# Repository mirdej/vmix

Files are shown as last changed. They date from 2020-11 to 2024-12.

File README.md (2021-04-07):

# ANYMIX 21

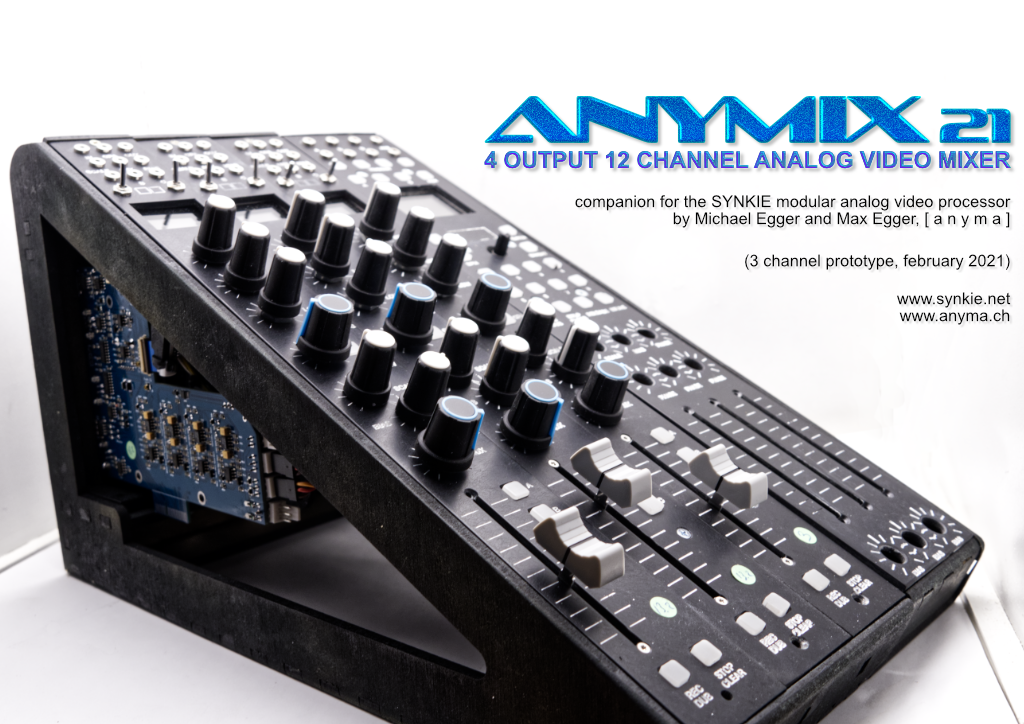
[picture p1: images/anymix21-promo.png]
Product Photo


Multichannel modular analog PAL video mixer based on the SYNKIE project

The Anymix21 is a 12 channel analog video mixer based on the paradigm of classic audio mixing desks.

Each channel is a complete SYNKIE by itself, sort of. It can handle anything from DC to around 10Mhz, this means you can mix CV signals with audio with PAL composite video signals. Contrary to an audio mixer, inputs are DC coupled, with 0v being black and 0.7V white level. Negative levels are permitted but will be clipped at the final output stage.

Each channel has a built-in equaliser, switchable edges (bandpass), comparator and inverter effects, and a scale-bias module for adjusting brightness and contrast. The signal can then be routed to 3 main output mix busses and an auxiliary output.

Apart from the equalizer, the effects and mix levels are digitally controlled analog, so parameters can be recorded, automated, or controlled externally through MIDI. The desk can be synchronized to a MIDI clock (which is then quantized to the vertical blanking interval derived from the genlock input).

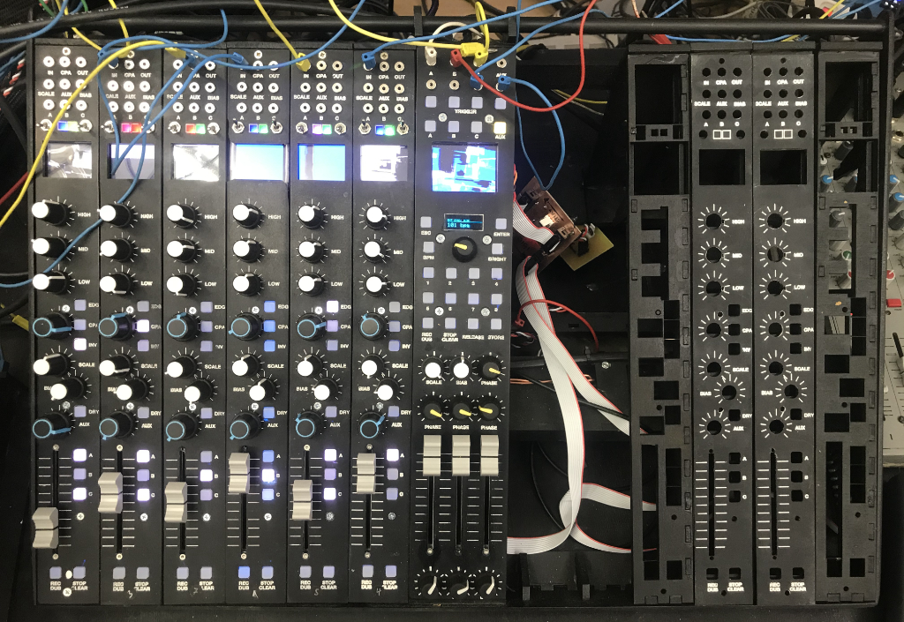
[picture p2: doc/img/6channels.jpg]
six channels


Still under construction, the first 6 channels have passed their endurance test running daily for weeks at the exhibiton “H.o.Me. – Heim für obsolete Medien” at Kunsthaus Langenthal.

### Documentation
- Architecture [Overview](./doc/architecture.md)
- Mixer Channel: [Flowchart and description](./doc/channel.md)
- Master Section: [Flowchart and description](./doc/master.md)

### Links
- [Build pictures and notes](https://www.anyma.ch/blogs/research/2021/04/07/building-the-anymix21/) on my blog
- [https://www.anyma.ch](https://www.anyma.ch)
- [https://www.synkie.net](https://www.synkie.net)
- [Videos on Vimeo](https://vimeo.com/showcase/8252873)
- [Synkie on Github](https://github.com/mirdej/synkie)

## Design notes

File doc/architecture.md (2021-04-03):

# Anymix 21 - Architecture

## Overview
The Anymix21 consists of one master module and 12 channel modules. Each module contains several separate PCBs that handle the signals. Two buses provide communcation between the master and all channels.

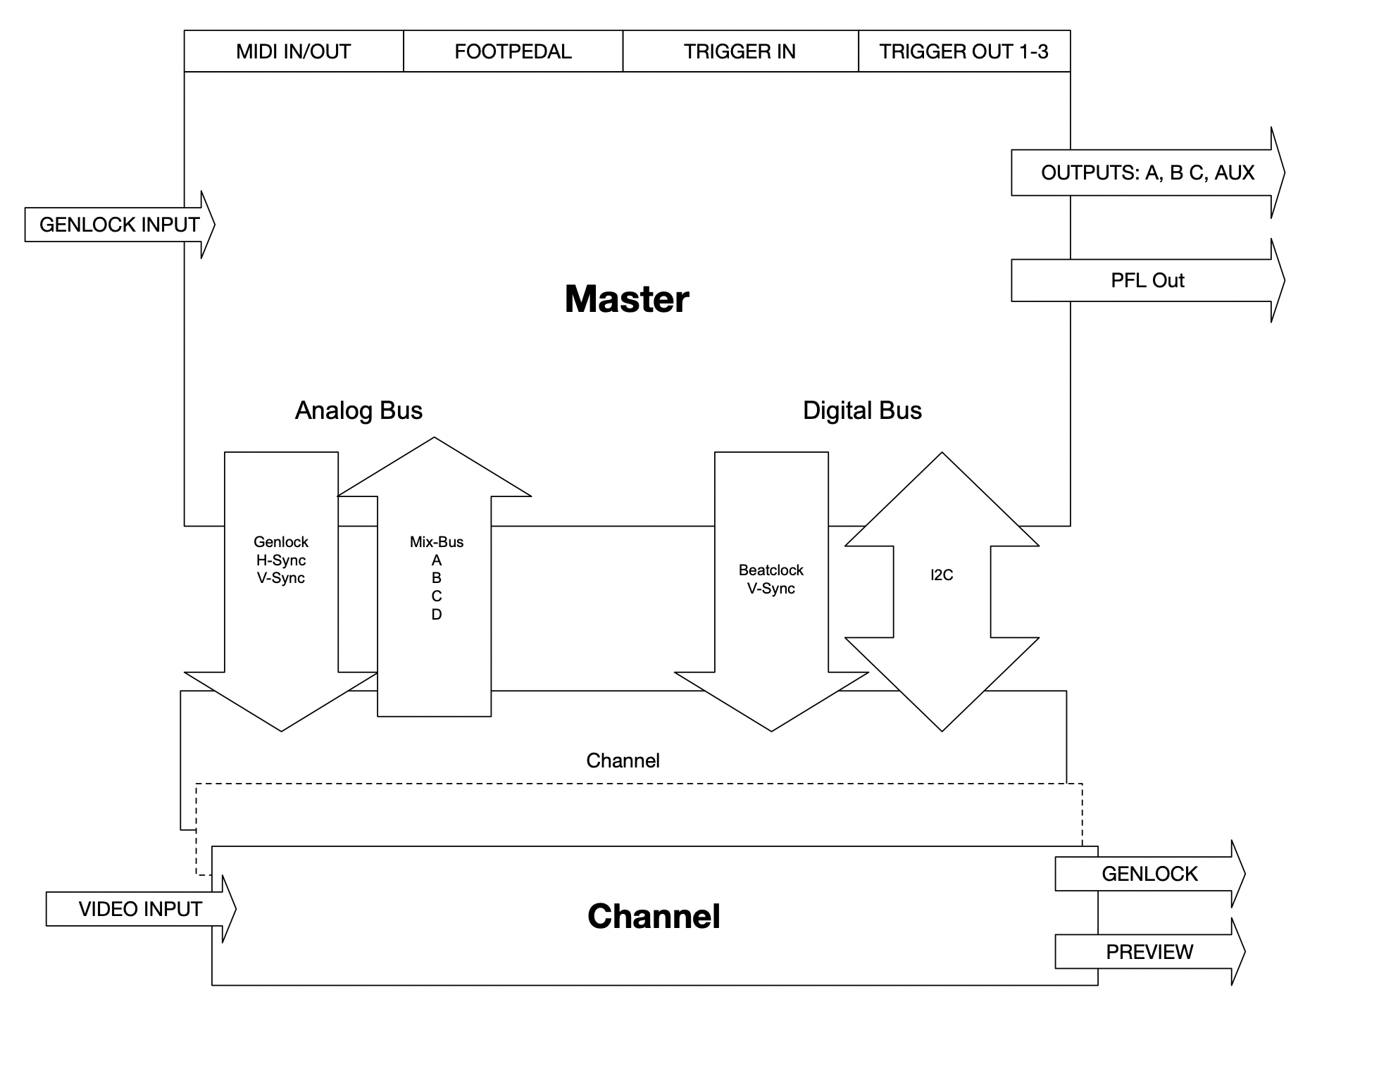
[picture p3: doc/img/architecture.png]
Architecture


### Analog Bus
The analog bus runs near the back side of the mixer. It is a series of PCBs with card edge connectors where the channel modules can plug into. It carries the cleaned-up genlock signal from the master module, timing signals: horizontal sync, backporch/burst, and vertical sync. The channel's four output VCAs connect to the four mixing lines on the analog bus.

### Digital Bus
Digital signals run near the front side of the mixer through a 10 pin IDC ribbon cable. It provides communication from/to the ESP32 on the master module and the Atmega1284s on each channel module.

The master provides the v-sync pulse (most processing on the channel modules is done in the verical blanking interval), as well as the beat-clock / quantization signal used to synchronize channel automation to the bpm clock of the master module.

An i2c bus provides bi-directional communication between the master and channel modules.

### Power
Each channel draws about 400mA on 5V and a bit less on -5V supply rails. I tried to follow a star/tree like topology for power as much as possible. Each channel connects to the supply through it's own cable. The vm101 module on each channel has resettable fuses and large decoupling capacitors, and in turn supplies power to the different boards in the module.

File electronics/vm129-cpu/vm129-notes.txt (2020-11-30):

Nov 18 2020

- cut out active video portion of genlock signal to prevent high freq spillover
- sync/oe inputs need level shifting
- built decent analog audio envelope follower for audio sync input

Nov 29
I2C Protocol
- Master->General Call: Start / Stop Automation	-> One byte, 0xf0 = Start, 0xf1 = Stop
- Master->General Call: Store / Recall Preset	-> Two bytes: 0xb0, 0x.. Store preset, 0xb1 0x.. Recall
- Master->Slave Write: MIDI -> Channel Settings -> Six bytes: Main, Aux, Bias, Scale, Compa, Buttons

- Master->Slave: Request (6 bytes)
 -> Slave->Master: Channel Settings

Slave: Set i2c address using buttons- store in eeprom
press Rec and stop buttons for 2 secs -> address set mode
press a/b/c/dry binary address
press rec -> save
or press stop -> cancel

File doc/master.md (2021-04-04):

# Anymix 21 - Master

## Signal Flow
At the center of the master module is the vm129-cpu board. It handles Genlock input, timing and communication with all the channel modules. Signals on the mix bus are mixed and buffered by vm107. Each of the four outputs has its own vm120 board that sets the master level and does the clipping and resynching to construct a standard PAL video signal from the often quite wild signals coming from the mix bus.
A separate vm128 board gets all signals pre- and post-fader and can output one preview signal on the central LCD monitor as well as on the preview out BNC connector on the backside of the mixer.

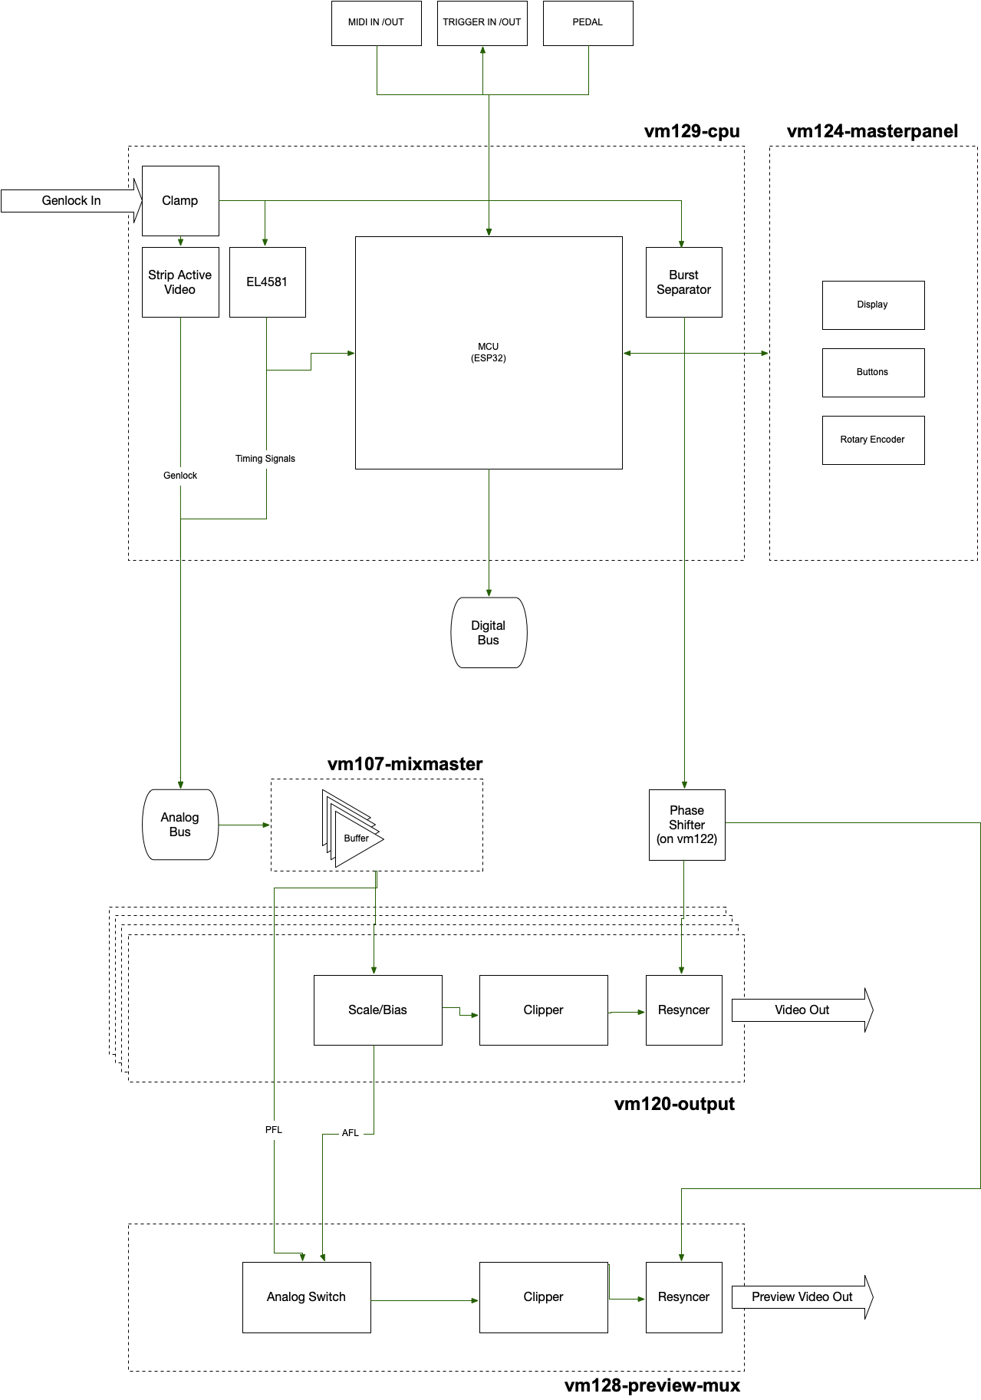
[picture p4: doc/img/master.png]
Flowchart


To compensate for the phase shit of the mix signal due to the processing on the channel boards, the colorburst seperated from genlock can be freely shifted up to 180 degrees before being cut into the output signal.

## Synchronisation

There are two sync mechanisms running interlocked in parallel on the mixer: Beat Clock and Video Sync

### 1) Beat Clock: 
This clock ticks 24 times per beat, running either on an internal precision timer 
set to a specific BPM, or driven externally via MIDI realtime messages.
Trigger outputs and parameter automation runs in step with the beat clock, but quantized to vsync (see below)

Clock period varies between ~30ms @ 80bpm down to ~11ms @ 220bpm

### 2) Video Sync:
Vertical blanking interrupts taken from the Genlock signal (via the EL4581) are the main clock for all mixer operations. Most of digital communication and noisy behaviour (Neopixel updates, we're looking at you) take place during vertical blanking.
Clock period: fixed at 20ms

## Synkietext
Synkietext lets us embed information in the vertical blanking interval, much like has been done with Teletext. For the time being, the beat clock signal is inserted into line 22, so it can be recorded on tape and later be used to make synchronized obverdubs. But plans are to add the ability to embed digital information to subsequent lines, sort of like EXIF data in digital photography.

vm129 reads Synkietext from the Genlock signal. vm120 can insert Synkietext into the output signal.

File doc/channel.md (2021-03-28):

# Anymix 21 - Channel

## Signal Flow
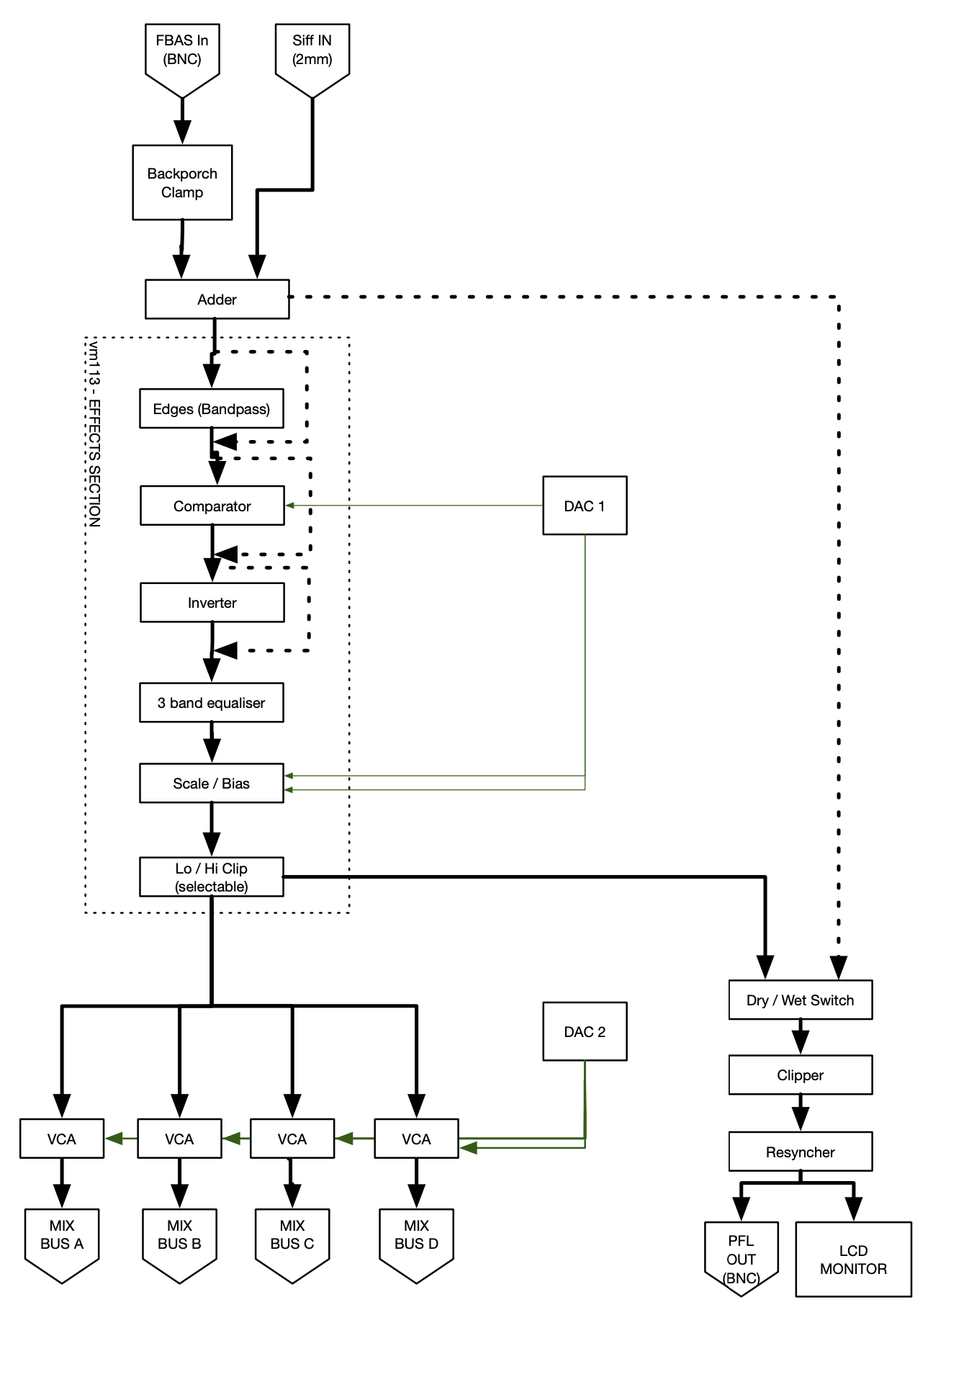
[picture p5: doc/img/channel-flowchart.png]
Flowchart

Standard PAL composite video coming from the backside BNC input is first clamped to ground and then mixed to any signal present on the 2mm banana "SIFF" input. The result is fed to the vm113 effects board.

### vm113 effects
A bypassable bandpass highlights edges in the image. An optional comparator will separate the picture into black/white, the threshold is set by the digital to analog converter.
An optional inverter turns whites to blacks and blacks to whites, it also inverts colors.

The signal then passes a 3 band equaliser. This part is not digitally controlled, the potentiometers act on the actual analog signal.
Hi frequency is set around the color subcarrier frequency of 4.433 Mhz - removes or adds saturation.
Mid is around 15.6 kHz, the horizontal line frequency. Low is somwhere lower, we're still not very clear where, and where it should be ;-)

The scale and bias is again digitally controlled, so it can be automated or recorded in a preset.

Finally the signal can be clipped at 1V/0V separately.
Not clipping the low end will result in the signal erasing/pulling low other channels if it goes below GND - which can be very annoying but also very pleasant.

### Output stage
DAC2 controls the four voltage controlled amplifiers that send the signal to the mixing buses.

For previewing, the signal is clipped hard at 0/1V regardless of the clipper settings, then the resyncer cuts in sync tips and the colorburst coming from the genlock signal.
Colorburst is shifted to match the phase shift of the effects section.

The preview signal is fed to the LCD Monitor, as well as buffered and sent to the BNC preview out at the back of the mixer.

## PCBs

### vm102 inputs
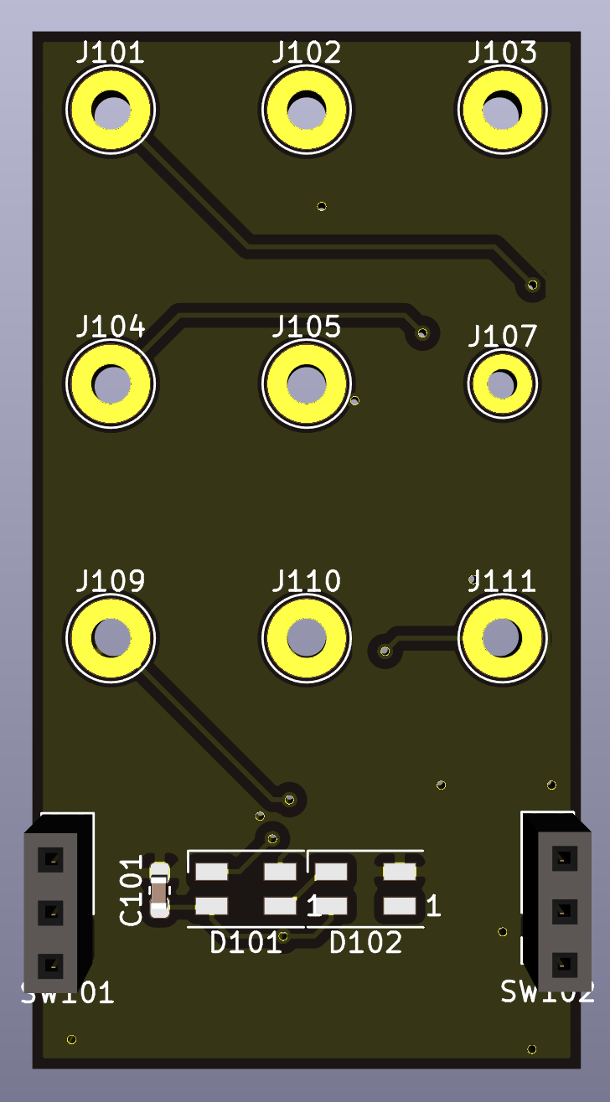
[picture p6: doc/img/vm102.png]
vm102

vm102 just gathers all the signals from/to the 2mm banana jacks into a FFC cable.
It also hosts the two clip switches and neopixels for the levelmeter

### vm101 in-out
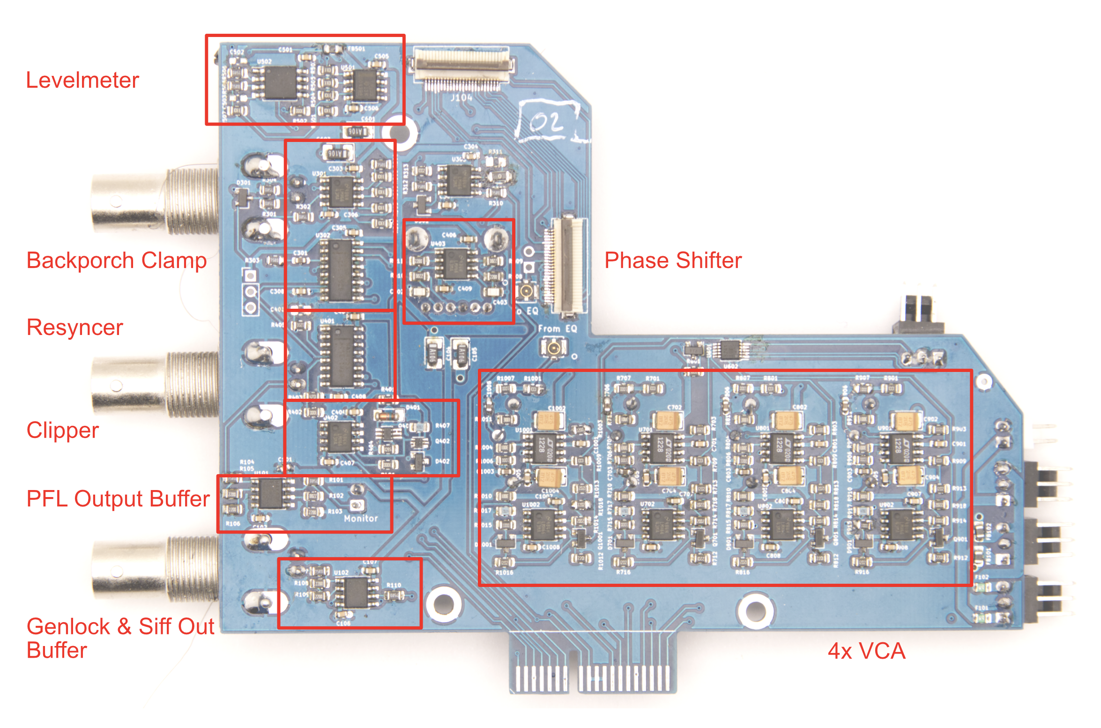
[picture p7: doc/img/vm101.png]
vm101

vm101 provides the backporch clamp for the BNC composite input and the mixer for the banana SIFF input. Preview out is resynched for the LCD monitor and the BNC PFL output.
4 voltage controlled amplifiers set the amount of signal that is sent on either mix bus.
Genlock signal from the mix bus is buffered and output through a third BNC connector.
An Attiny85 controls the levelmeter neopixels on vm102.
vm1010 connects to vm102 and vm113 through FFC cables.
SPI signals from vm010 to the DAC come through a 3pin header.

### vm113-effects
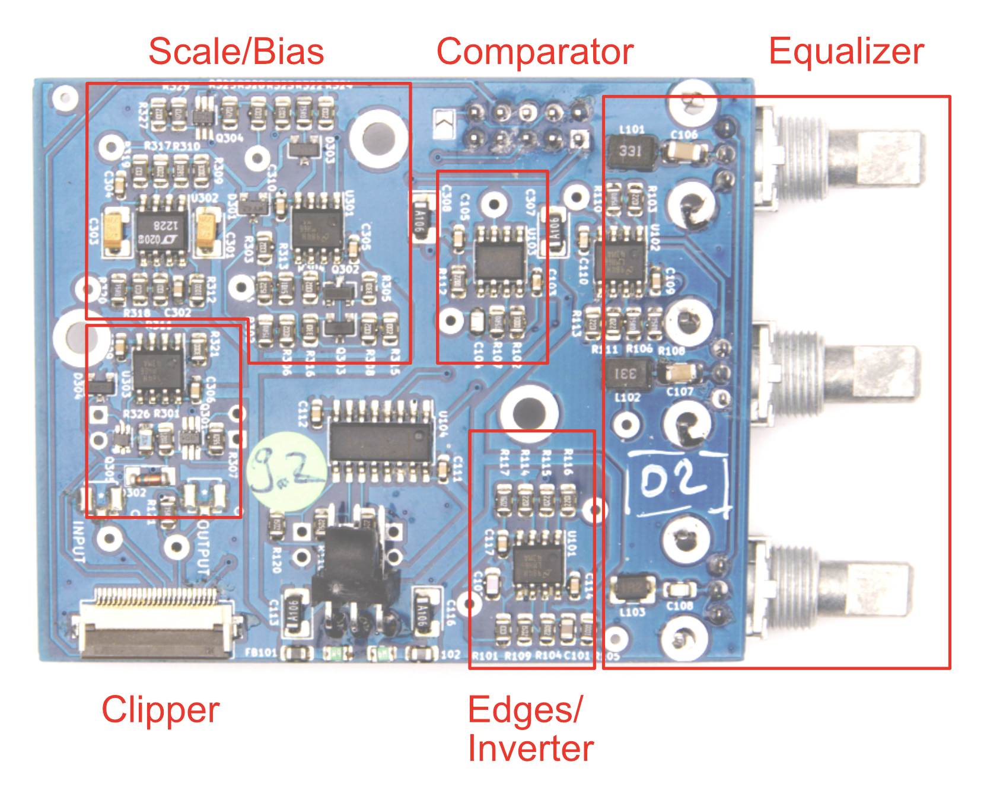
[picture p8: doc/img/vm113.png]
vm113

The different effect blocks are gathered around a MAX4053 analog switch that let's us bypass certain effects. An FFC cable connects to vm101 and the banana plugs on the frontpanel.
Control signals from vm010 come through a 10pin IDC.

### vm010-control
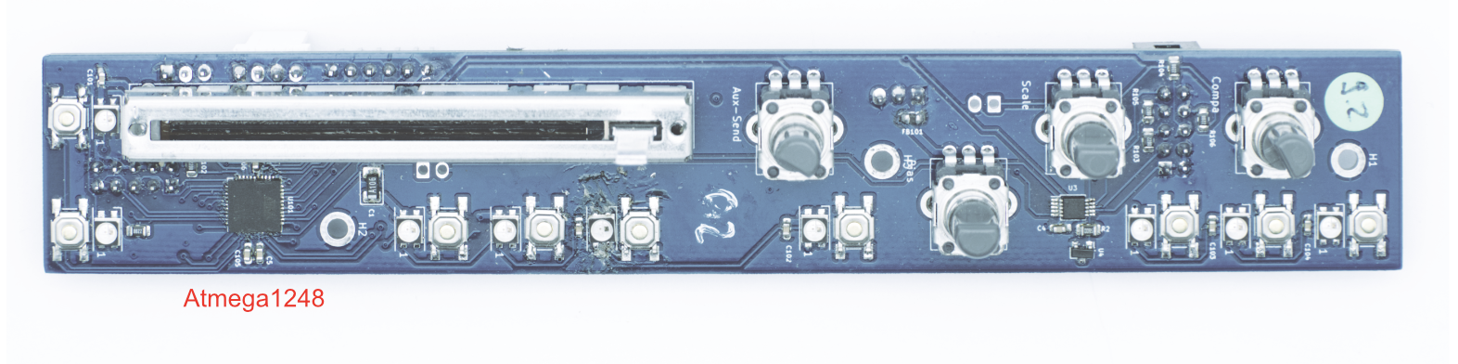
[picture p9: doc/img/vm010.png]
vm010

User input is sampled by the Atmega1248 at every vertical blanking interval. This microcontroiller has enough RAM to record and playback around 40 seconds of user interaction.
A MAX5741 generates the control voltages for the vm113 effects board. A second MAX5741 on vm101 is controlled through SPI. Communication with the master controller vm129 takes place through I2C over the 10pin IDC digital bus.

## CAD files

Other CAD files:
electronics/vm129-cpu/beatcalc.skp
electronics/vm129-cpu/beatcalc~.skp
sketchup/mixer-cage.skp
sketchup/mixer-cage2.skp
sketchup/mixer-cage2~.skp
sketchup/mixer-cage~.skp
sketchup/skizze3.skp
sketchup/skizze3~.skp
sketchup/skizze4 copy.skp
sketchup/vmix test platform.skp

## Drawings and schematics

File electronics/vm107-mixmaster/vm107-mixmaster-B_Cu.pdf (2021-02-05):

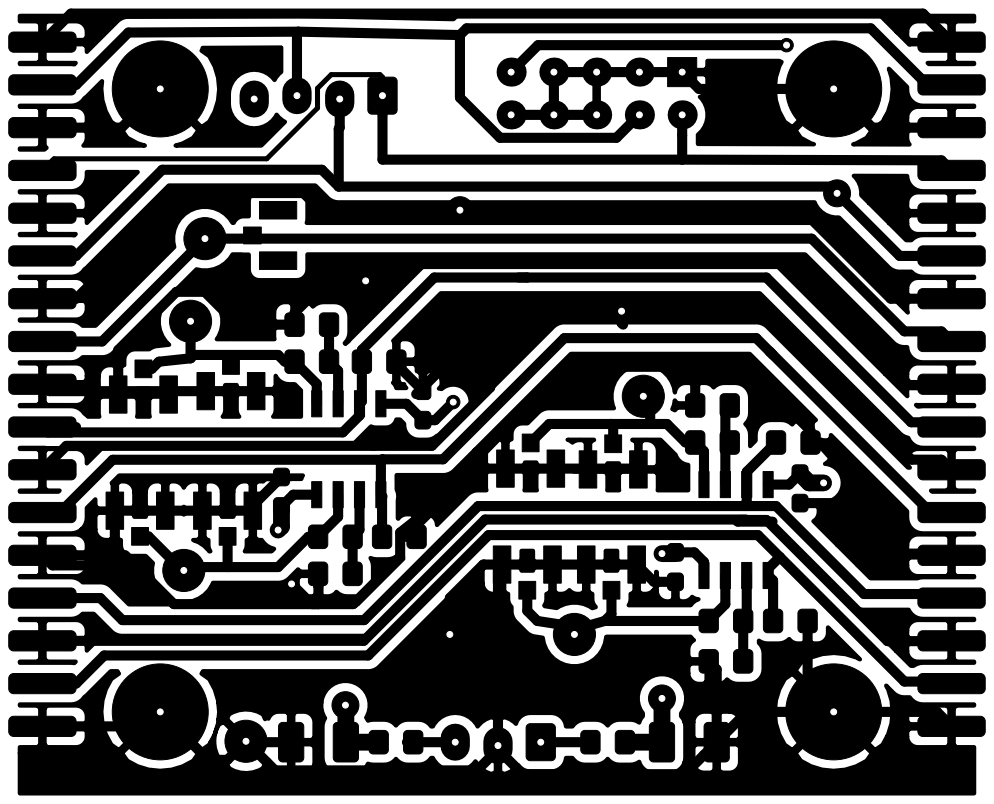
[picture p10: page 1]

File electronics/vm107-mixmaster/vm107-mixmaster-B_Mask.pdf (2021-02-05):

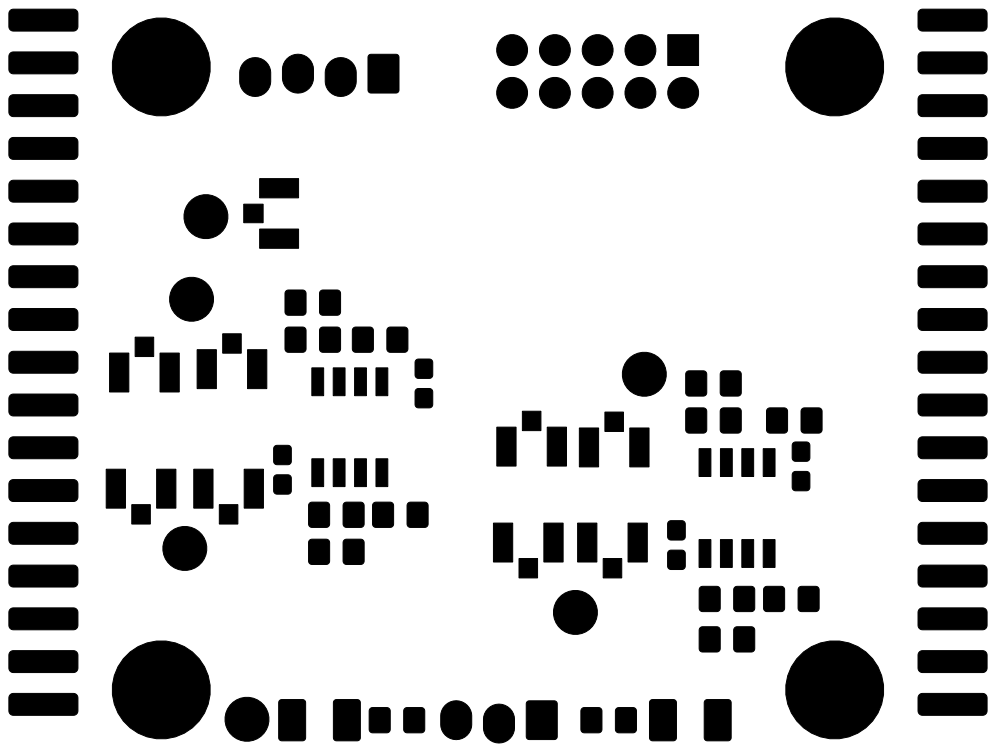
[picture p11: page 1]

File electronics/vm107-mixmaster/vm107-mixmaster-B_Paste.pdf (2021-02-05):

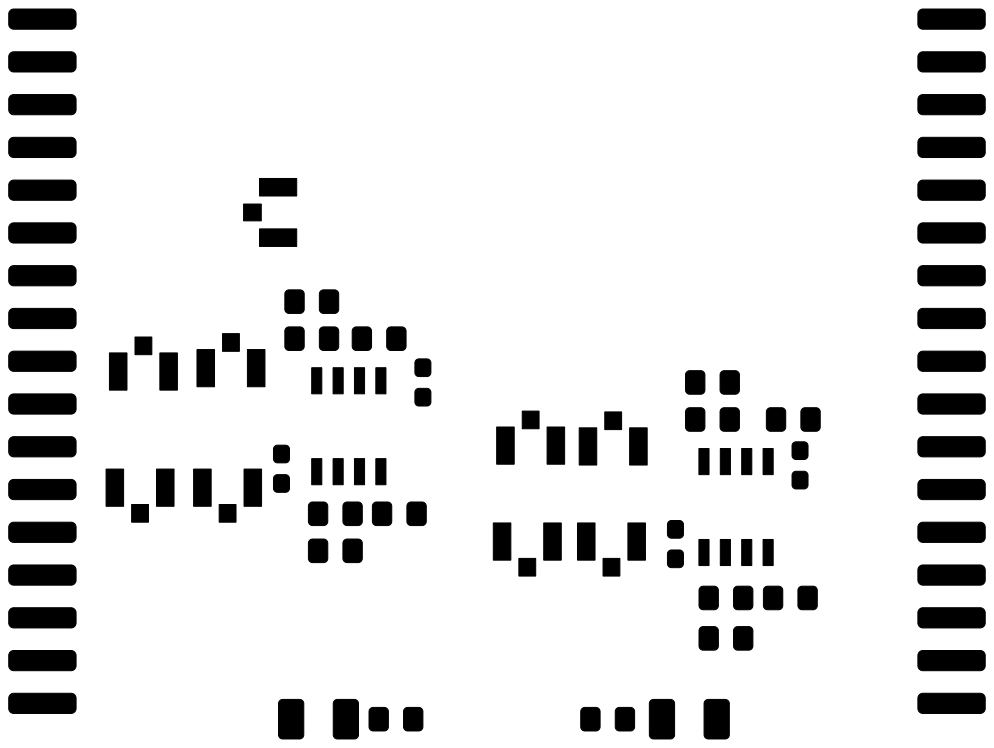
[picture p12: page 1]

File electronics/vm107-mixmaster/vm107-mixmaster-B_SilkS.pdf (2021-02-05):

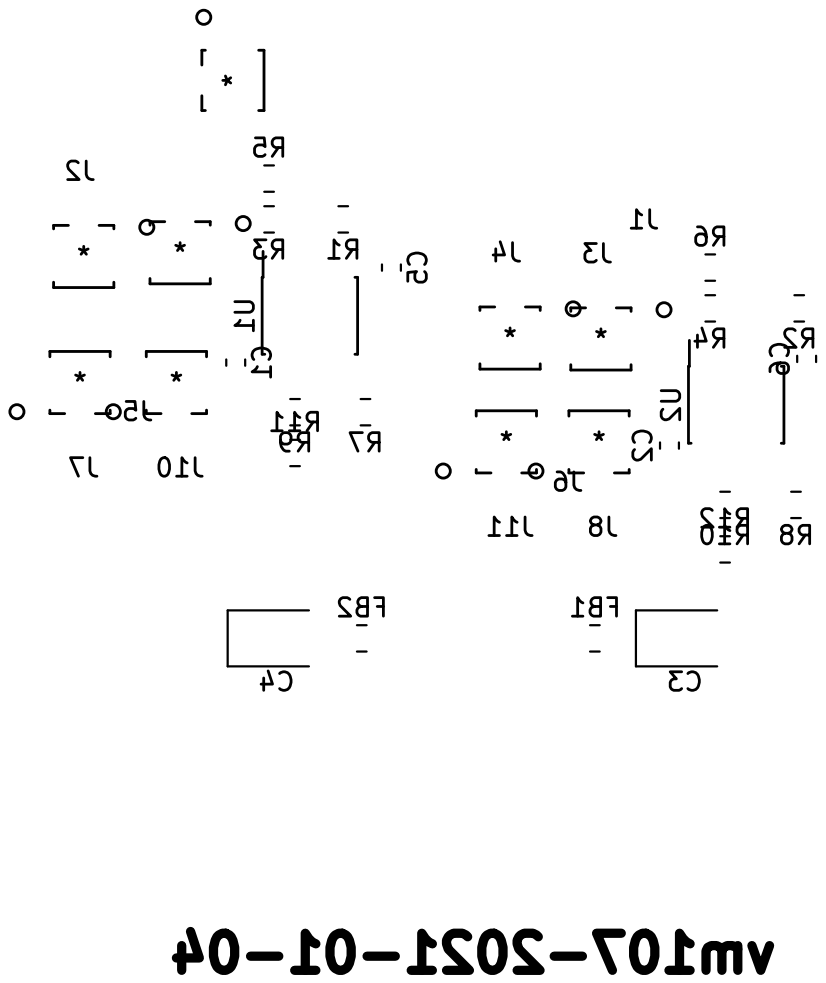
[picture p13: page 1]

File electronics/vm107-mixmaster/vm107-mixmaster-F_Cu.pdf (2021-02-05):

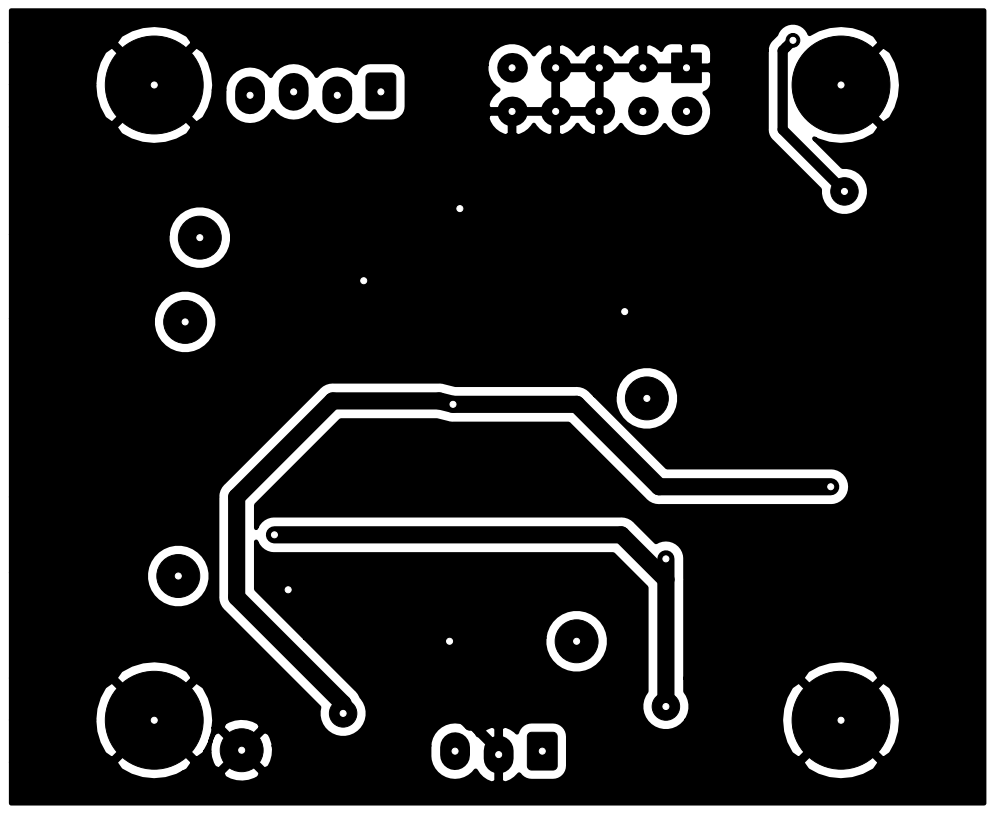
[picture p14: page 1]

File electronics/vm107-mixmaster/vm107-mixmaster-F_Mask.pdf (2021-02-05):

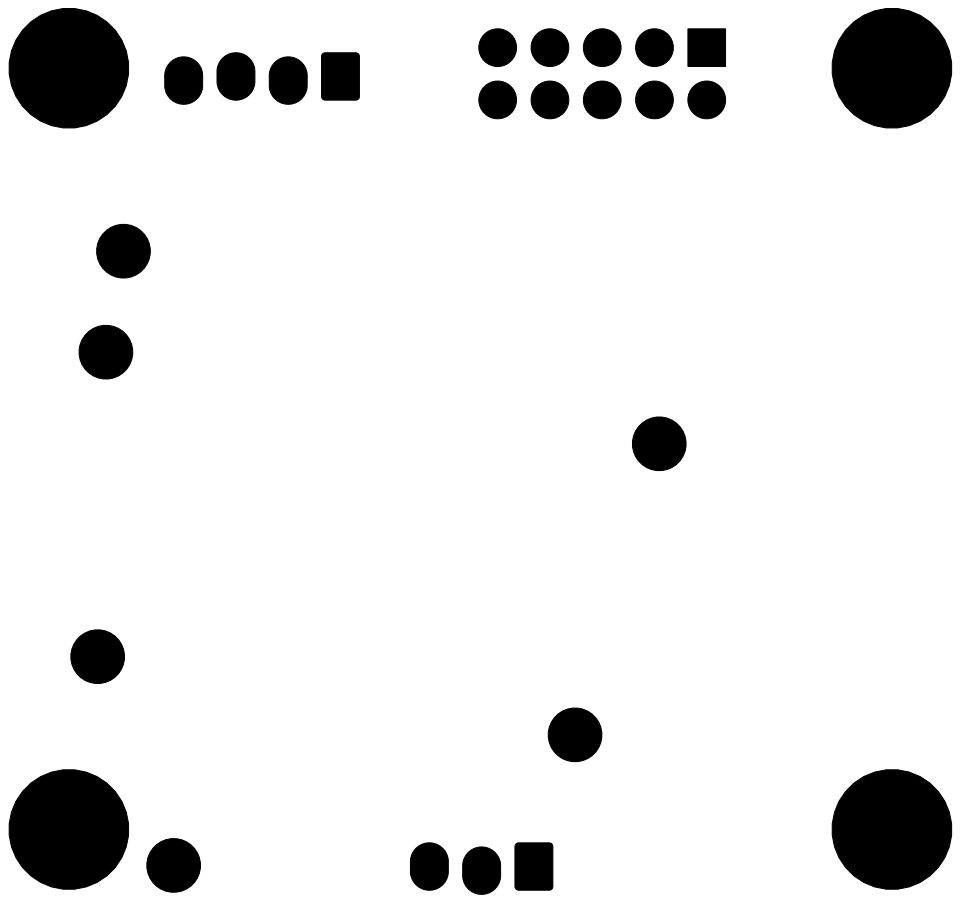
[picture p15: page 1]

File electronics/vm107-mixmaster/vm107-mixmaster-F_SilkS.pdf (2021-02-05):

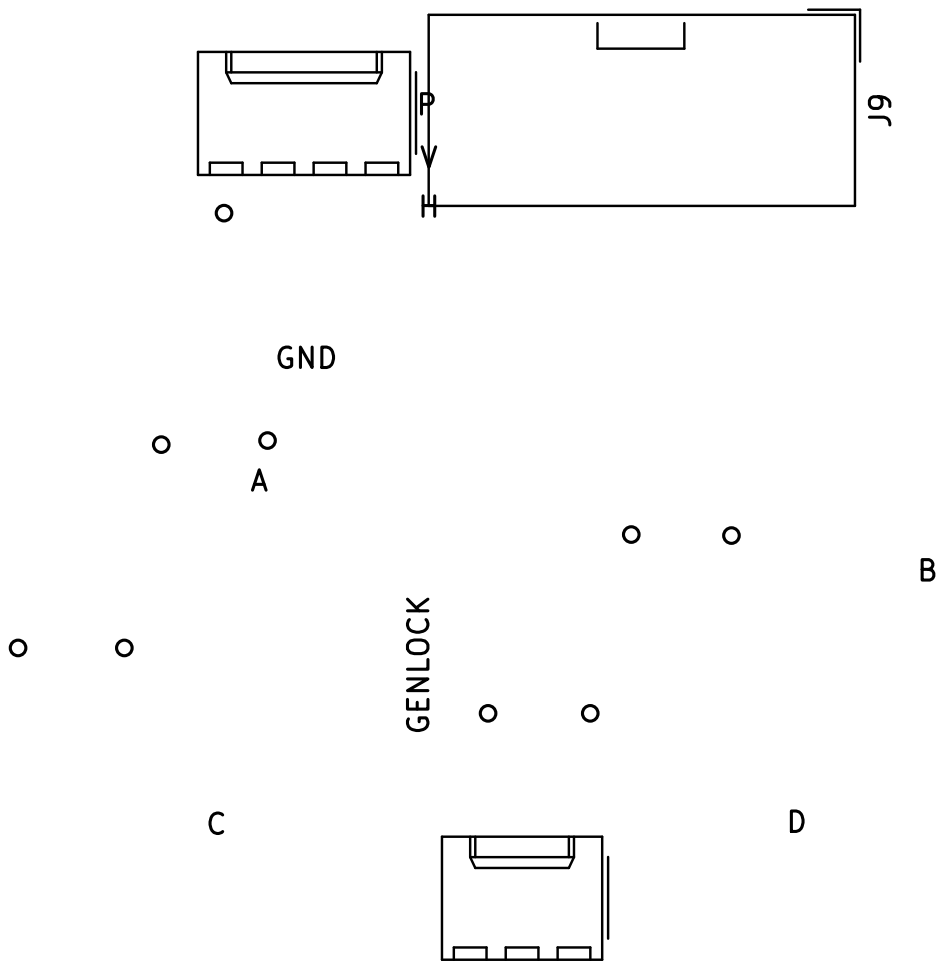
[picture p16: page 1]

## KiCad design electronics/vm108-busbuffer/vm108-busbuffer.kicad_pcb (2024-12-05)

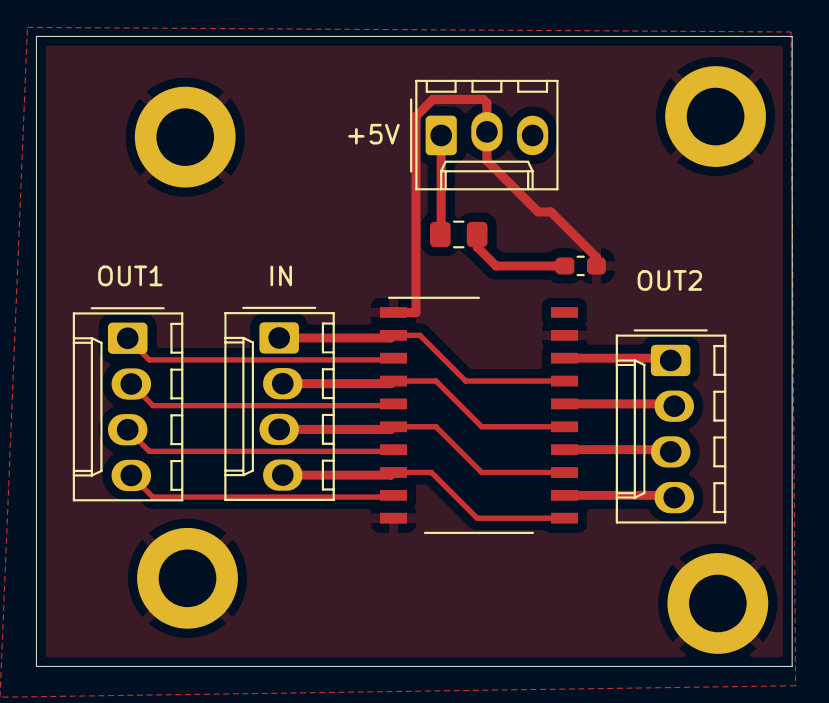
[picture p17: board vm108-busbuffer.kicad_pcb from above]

Board: 2 copper layers, 42.0 x 35.0 mm, 11 parts (0 on the bottom side), 15 nets.

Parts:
C1: C; R_0603_1608Metric_Pad1.05x0.95mm_HandSolder
FB1: Ferrite_Bead; L_0805_2012Metric_Pad1.15x1.40mm_HandSolder
H1, H2, H3, H4: MountingHole_Pad; MountingHole_3.2mm_M3_DIN965_Pad
J1: Supply; Molex_KK-254_AE-6410-03A_1x03_P2.54mm_Vertical
J2, J3, J4: Sync-Bus; Molex_KK-254_AE-6410-04A_1x04_P2.54mm_Vertical
U1: 74HC244; SO-20_12.8x7.5mm_P1.27mm

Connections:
+5V: C1.1, FB1.2, U1.20 (VCC)
/supply+: FB1.1, J1.1
GND: C1.2, H1.1, H2.1, H3.1, H4.1, J1.2, U1.1 (1OE), U1.10 (GND), U1.19 (2OE)
unnamed: J2.1, U1.2 (1A0), U1.17 (2A0)
unnamed: J2.2, U1.4 (1A1), U1.15 (2A1)
unnamed: J2.3, U1.6 (1A2), U1.13 (2A2)
unnamed: J2.4, U1.8 (1A3), U1.11 (2A3)
unnamed: J3.1, U1.18 (1Y0)
unnamed: J3.2, U1.16 (1Y1)
unnamed: J3.3, U1.14 (1Y2)
unnamed: J3.4, U1.12 (1Y3)
unnamed: J4.1, U1.3 (2Y0)
unnamed: J4.2, U1.5 (2Y1)
unnamed: J4.3, U1.7 (2Y2)
unnamed: J4.4, U1.9 (2Y3)

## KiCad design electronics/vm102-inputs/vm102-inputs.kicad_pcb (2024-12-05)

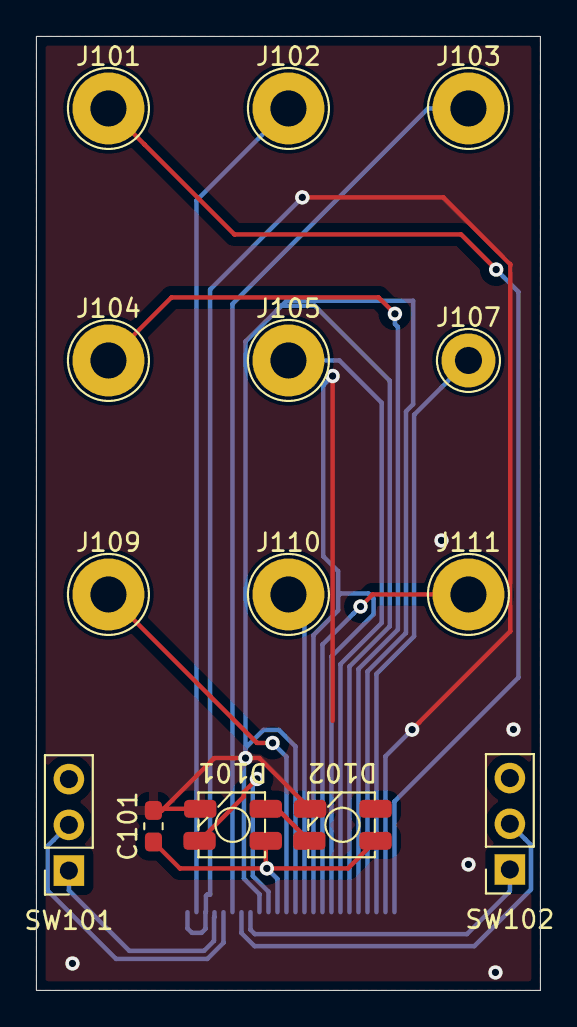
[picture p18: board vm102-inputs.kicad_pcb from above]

Board: 2 copper layers, 28.0 x 53.0 mm, 15 parts (1 on the bottom side), 17 nets.

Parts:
C101: C; C_0603_1608Metric_Pad1.05x0.95mm_HandSolder
D101, D102: SK6812MINI; SK6812-MINI-HS
J101, J102, J103, J104, J105, J109, J110, J111: Conn; TestPoint_THTPad_D4.0mm_Drill2.0mm
J106: Conn_01x24_Shielded; Hirose_FH12-24S-0.5SH_1x24-1MP_P0.50mm_Horizontal
J107: Conn; TestPoint_THTPad_D3.0mm_Drill1.5mm
SW101, SW102: SW_SPDT; PinSocket_1x03_P2.54mm_Vertical

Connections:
/a: J106.12, J109.1
/aux: J105.1, J106.18
/b: J106.14, J110.1
/bias: J106.22, J107.1
/c: J106.16, J111.1
/compa-out: J102.1, J106.2
/hi_clip1: J106.8, SW102.1 (A)
/hi_clip2: J106.7, SW102.2 (B)
/lo_clip1: J106.4, SW101.1 (A)
/lo_clip2: J106.5, SW101.2 (B)
/output: J103.1, J106.6
/pixels: D101.3 (DIN), J106.10
/scale: J104.1, J106.20
/siff-in: J101.1, J106.24
GND: C101.2, D101.2 (VSS), D102.2 (VSS), J106.1, J106.3, J106.9, J106.13, J106.15, J106.17, J106.19, J106.21, J106.23
unnamed: D101.1 (DOUT), D102.3 (DIN)
VCC: C101.1, D101.4 (VDD), D102.4 (VDD), J106.11

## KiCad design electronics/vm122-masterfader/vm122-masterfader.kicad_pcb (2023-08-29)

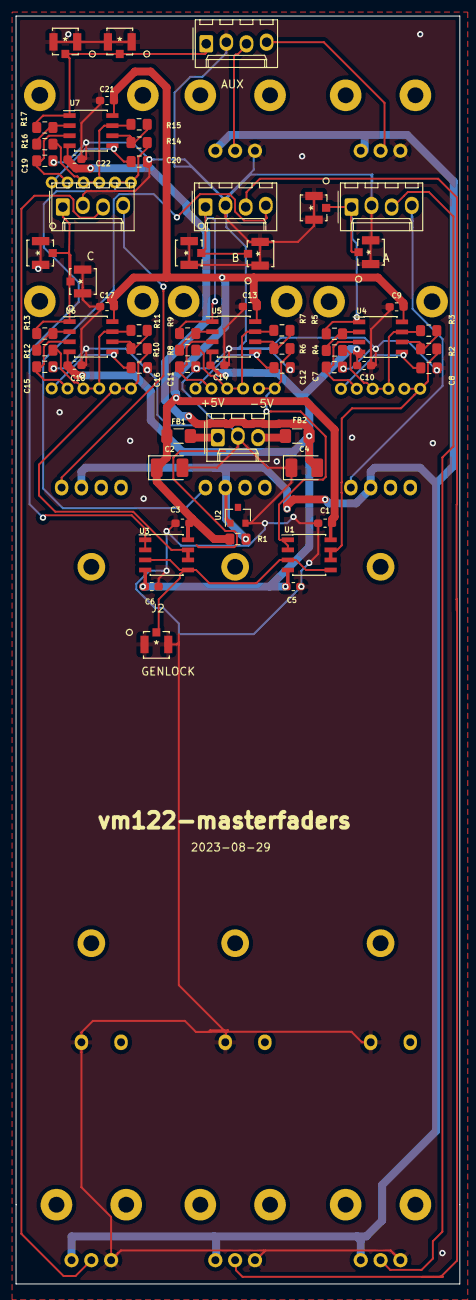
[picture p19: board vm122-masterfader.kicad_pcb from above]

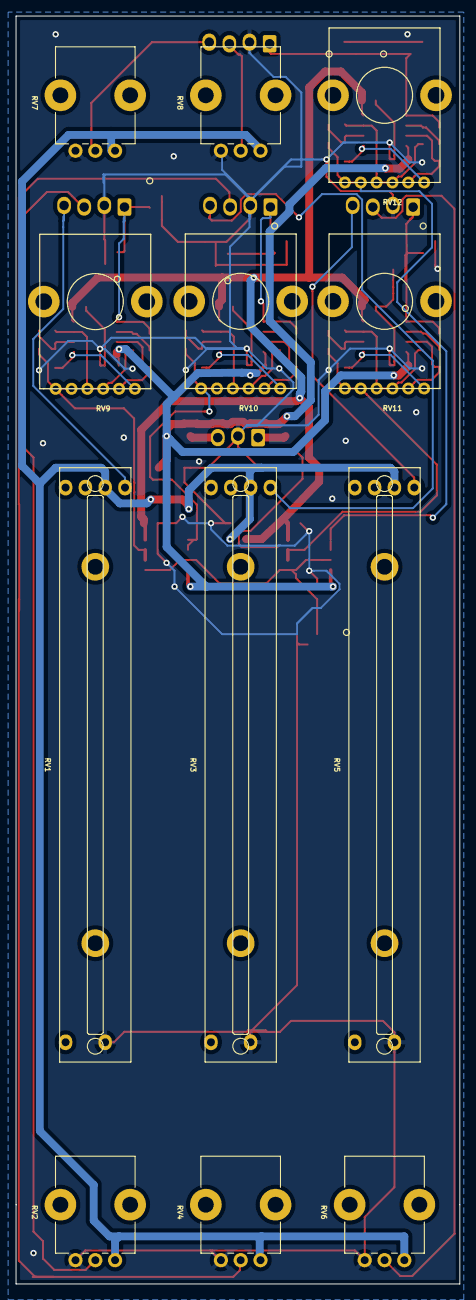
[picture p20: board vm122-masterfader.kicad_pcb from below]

Board: 2 copper layers, 56.0 x 160.0 mm, 74 parts (12 on the bottom side), 43 nets.

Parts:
C1, C3, C5, C6, C9, C10, C13, C14, C17, C18, C21, C22: 100n; C_0603_1608Metric_Pad1.05x0.95mm_HandSolder
C2, C4: CP; CP_EIA-3528-21_Kemet-B_Pad1.50x2.35mm_HandSolder
C7, C8, C11, C12, C15, C16, C19, C20: 10p; C_0805_2012Metric_Pad1.15x1.40mm_HandSolder
FB1, FB2: Ferrite_Bead; L_1206_3216Metric_Pad1.42x1.75mm_HandSolder
J1: Conn_01x03; Molex_KK-254_AE-6410-03A_1x03_P2.54mm_Vertical
J2, J7, J8, J9, J10, J11, J12, J13, J14: UMCC; TE_UMCC_2337019-1
J3: A; Molex_KK-254_AE-6410-04A_1x04_P2.54mm_Vertical
J4: B; Molex_KK-254_AE-6410-04A_1x04_P2.54mm_Vertical
J5: C; Molex_KK-254_AE-6410-04A_1x04_P2.54mm_Vertical
J6: D; Molex_KK-254_AE-6410-04A_1x04_P2.54mm_Vertical
R1: 560; R_0805_2012Metric_Pad1.15x1.40mm_HandSolder
R2, R3, R4, R5, R6, R7, R8, R9, R10, R11, R12, R13, R14, R15, R16, R17: 220; R_0805_2012Metric_Pad1.15x1.40mm_HandSolder
RV1, RV3, RV5: SCALE; Potentiometer_Alps_RS6011xP_Slide
RV2, RV4, RV6, RV8: BIAS; Potentiometer_Alps_RK09K_Single_Vertical
RV7: SCALE; Potentiometer_Alps_RK09K_Single_Vertical
RV9, RV10, RV11, RV12: R_POT_Dual; RK12L123
U1, U3, U4, U5, U6, U7: LMH6643; SOIC-8_3.9x4.9mm_P1.27mm
U2: ADR510; SOT-23

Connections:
+5V: C1.1, C2.1, C3.1, C9.2, C13.2, C17.2, C21.2, FB1.1, R1.1, U1.8 (V+), U3.8 (V+), U4.8 (V+), U5.8 (V+), U6.8 (V+), U7.8 (V+)
-5V: C4.2, C5.1, C6.1, C10.1, C14.1, C18.1, C22.1, FB2.1, U1.4 (V-), U3.4 (V-), U4.4 (V-), U5.4 (V-), U6.4 (V-), U7.4 (V-)
/Phase1/INPUT: R2.2, RV9.1, RV9.2, U1.6 (-), U1.7
/Phase1/OUTPUT: J3.1, J7.1, J8.1, R5.1, U4.1
/sheet5FF0F8E5/INPUT: R10.2, RV11.1, RV11.2, U3.6 (-), U3.7
/sheet5FF0F8E5/OUTPUT: J5.1, J11.1, J12.1, R13.1, U6.1
/sheet5FF0F40B/INPUT: R6.2, RV10.1, RV10.2, U1.1, U1.2 (-)
/sheet5FF0F40B/OUTPUT: J4.1, J9.1, J10.1, R9.1, U5.1
/sheet5FF0F904/INPUT: R14.2, RV12.1, RV12.2, U3.1, U3.2 (-)
/sheet5FF0F904/OUTPUT: J6.1, J13.1, J14.1, R17.1, U7.1
GND: C1.2, C2.2, C3.2, C4.1, C5.2, C6.2, C7.2, C8.2, C9.1, C10.2, C11.2, C12.2, C13.1, C14.2, C15.2, C16.2, C17.1, C18.2, C19.2, C20.2, C21.1, C22.2, J1.2, J2.2, J2.3, J3.2, J4.2, J5.2, J6.2, J7.2, J7.3, J8.2, J8.3, J9.2, J9.3, J10.2, J10.3, J11.2, J11.3, J12.2, J12.3, J13.2, J13.3, J14.2, J14.3, RV1.3, RV2.3, RV3.3, RV4.3, RV5.3, RV6.3, RV7.3, RV8.3, U2.2 (V-)
unnamed: C7.1, RV9.6, U4.3 (+)
unnamed: C8.1, RV9.3, U4.5 (+)
unnamed: C11.1, RV10.6, U5.3 (+)
unnamed: C12.1, RV10.3, U5.5 (+)
unnamed: C15.1, RV11.6, U6.3 (+)
unnamed: C16.1, RV11.3, U6.5 (+)
unnamed: C19.1, RV12.6, U7.3 (+)
unnamed: C20.1, RV12.3, U7.5 (+)
unnamed: FB1.2, J1.1
unnamed: FB2.2, J1.3
unnamed: J3.3, RV2.2
unnamed: J3.4, RV1.2
unnamed: J4.3, RV4.2
unnamed: J4.4, RV3.2
unnamed: J5.3, RV6.2
unnamed: J5.4, RV5.2
unnamed: J6.3, RV8.2
unnamed: J6.4, RV7.2
unnamed: R2.1, R3.2, U4.6 (-)
unnamed: R3.1, R4.2, RV9.4, RV9.5, U4.7
unnamed: R4.1, R5.2, U4.2 (-)
unnamed: R6.1, R7.2, U5.6 (-)
unnamed: R7.1, R8.2, RV10.4, RV10.5, U5.7
unnamed: R8.1, R9.2, U5.2 (-)
unnamed: R10.1, R11.2, U6.6 (-)
unnamed: R11.1, R12.2, RV11.4, RV11.5, U6.7
unnamed: R12.1, R13.2, U6.2 (-)
unnamed: R14.1, R15.2, U7.6 (-)
unnamed: R15.1, R16.2, RV12.4, RV12.5, U7.7
unnamed: R16.1, R17.2, U7.2 (-)
unnamed: J2.1, U1.3 (+), U1.5 (+), U3.3 (+), U3.5 (+)
VCCQ: R1.2, RV1.1, RV2.1, RV3.1, RV4.1, RV5.1, RV6.1, RV7.1, RV8.1, U2.1 (V+)

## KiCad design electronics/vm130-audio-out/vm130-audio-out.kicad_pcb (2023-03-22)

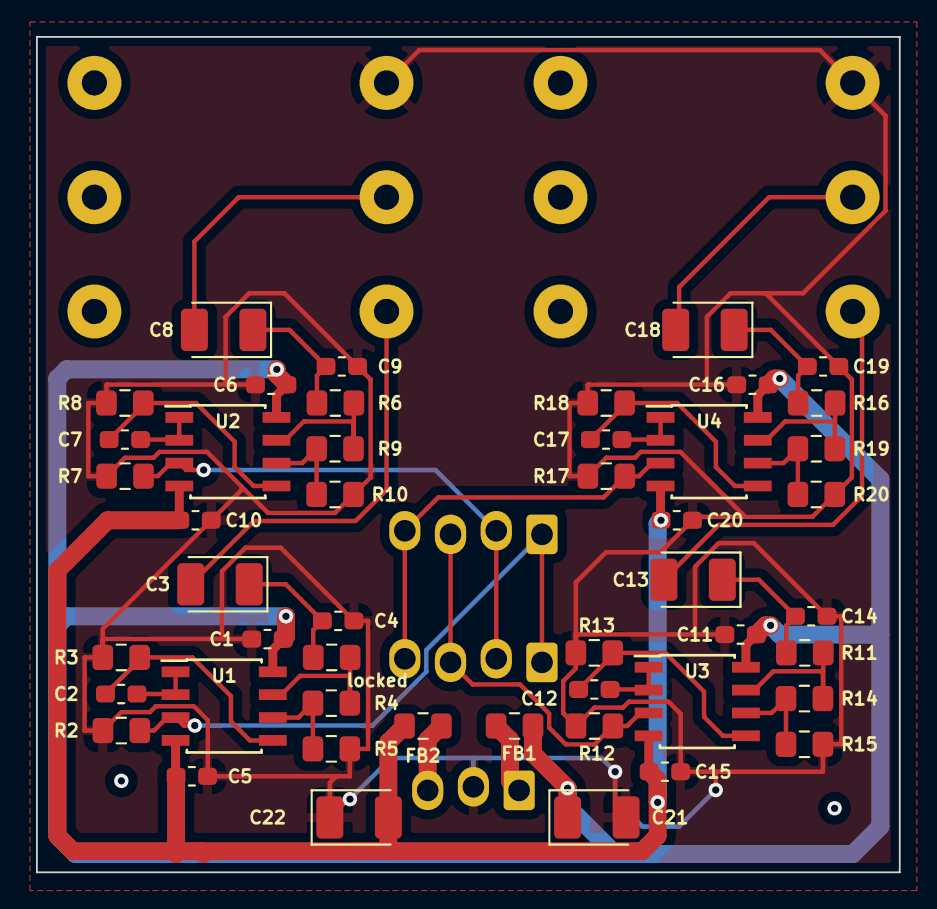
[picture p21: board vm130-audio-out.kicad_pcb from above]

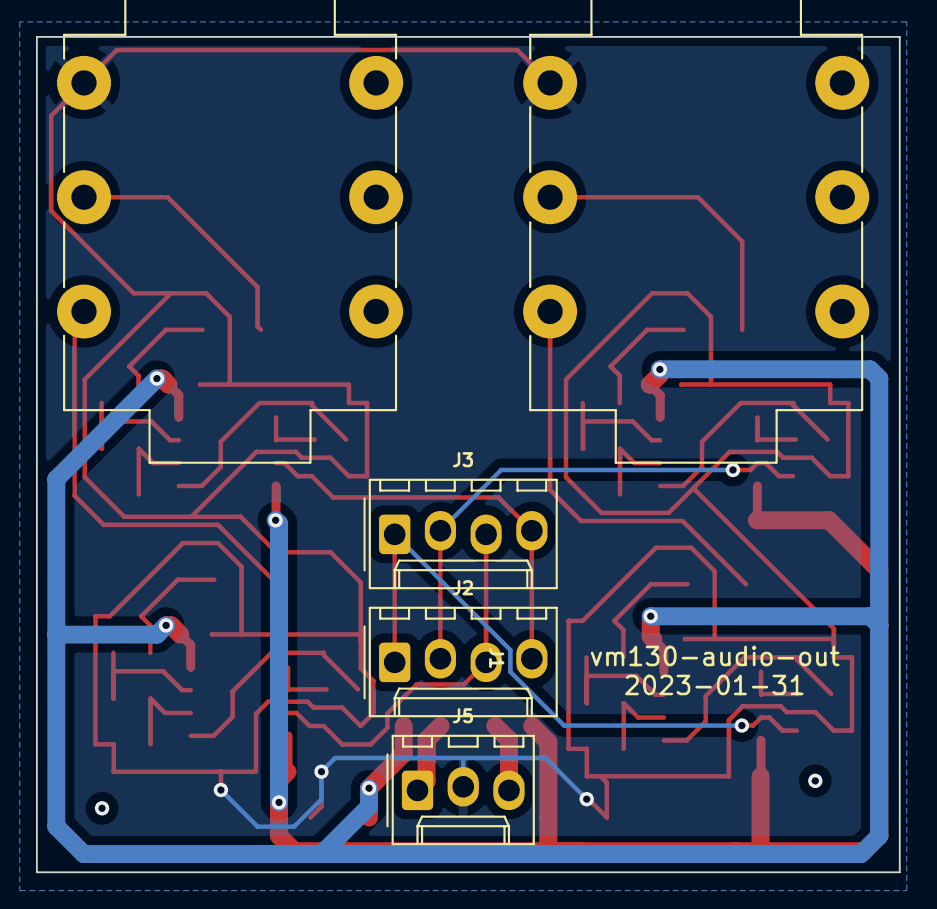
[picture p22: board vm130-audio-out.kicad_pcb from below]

Board: 2 copper layers, 47.9 x 46.4 mm, 53 parts (5 on the bottom side), 33 nets.

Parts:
C1, C4, C5, C6, C9, C10, C11, C14, C15, C16, C19, C20: 100n; C_0603_1608Metric_Pad1.05x0.95mm_HandSolder
C2, C7, C12, C17: 1u; C_0603_1608Metric_Pad1.05x0.95mm_HandSolder
C3, C8, C13, C18: 100u; CP_EIA-3528-21_Kemet-B_Pad1.50x2.35mm_HandSolder
C21, C22: CP; CP_EIA-3528-21_Kemet-B_Pad1.50x2.35mm_HandSolder
FB1, FB2: FerriteBead; L_0805_2012Metric_Pad1.15x1.40mm_HandSolder
J1, J4: AudioJack3_Switch; Jack_6.35mm_Neutrik_NMJ6HCD3_Horizontal
J2, J3: Conn_01x04; Molex_KK-254_AE-6410-04A_1x04_P2.54mm_Vertical
J5: Conn_01x03; Molex_KK-254_AE-6410-03A_1x03_P2.54mm_Vertical
R2, R7, R12, R17: 47k; C_0805_2012Metric_Pad1.15x1.40mm_HandSolder
R3, R8, R13, R18: 10k; C_0805_2012Metric_Pad1.15x1.40mm_HandSolder
R4, R5, R9, R10, R14, R15, R19, R20: 500; C_0805_2012Metric_Pad1.15x1.40mm_HandSolder
R6, R11, R16: 75; C_0805_2012Metric_Pad1.15x1.40mm_HandSolder
U1, U2, U3, U4: Opamp_Dual_Generic; SOIC-8_3.9x4.9mm_P1.27mm
locked: 75; C_0805_2012Metric_Pad1.15x1.40mm_HandSolder

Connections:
+5V: C1.2, C6.2, C11.2, C16.2, C21.1, FB1.2, U1.8 (V+), U2.8 (V+), U3.8 (V+), U4.8 (V+)
-5V: C5.2, C10.2, C15.2, C20.2, C22.2, FB2.2, U1.4 (V-), U2.4 (V-), U3.4 (V-), U4.4 (V-)
/channel1/out: C8.2, J1.R
/channel2/out: C13.2, J4.T
/channel3/out: C18.2, J4.R
/channel/out: C3.2, J1.T
/in-a: J2.1, J3.1, R2.1, U1.3 (+)
/in-b: J2.2, J3.2, R7.1, U2.3 (+)
/in-c: J2.3, J3.3, R12.1, U3.3 (+)
/in-d: J2.4, J3.4, R17.1, U4.3 (+)
GND: C1.1, C4.1, C5.1, C6.1, C9.1, C10.1, C11.1, C14.1, C15.1, C16.1, C19.1, C20.1, C21.2, C22.1, J1.S, J4.S, J5.2, R2.2, R3.2, R5.2, R7.2, R8.2, R10.2, R12.2, R13.2, R15.2, R17.2, R18.2, R20.2
unnamed: C2.1, U1.1, U1.2 (-)
unnamed: C2.2, R3.1, U1.5 (+)
unnamed: C3.1, C4.2, locked.2
unnamed: C7.1, U2.1, U2.2 (-)
unnamed: C7.2, R8.1, U2.5 (+)
unnamed: C8.1, C9.2, R6.2
unnamed: C12.1, U3.1, U3.2 (-)
unnamed: C12.2, R13.1, U3.5 (+)
unnamed: C13.1, C14.2, R11.2
unnamed: C17.1, U4.1, U4.2 (-)
unnamed: C17.2, R18.1, U4.5 (+)
unnamed: C18.1, C19.2, R16.2
unnamed: FB1.1, J5.1
unnamed: FB2.1, J5.3
unnamed: R4.2, U1.7, locked.1
unnamed: R4.1, R5.1, U1.6 (-)
unnamed: R6.1, R9.2, U2.7
unnamed: R9.1, R10.1, U2.6 (-)
unnamed: R11.1, R14.2, U3.7
unnamed: R14.1, R15.1, U3.6 (-)
unnamed: R16.1, R19.2, U4.7
unnamed: R19.1, R20.1, U4.6 (-)

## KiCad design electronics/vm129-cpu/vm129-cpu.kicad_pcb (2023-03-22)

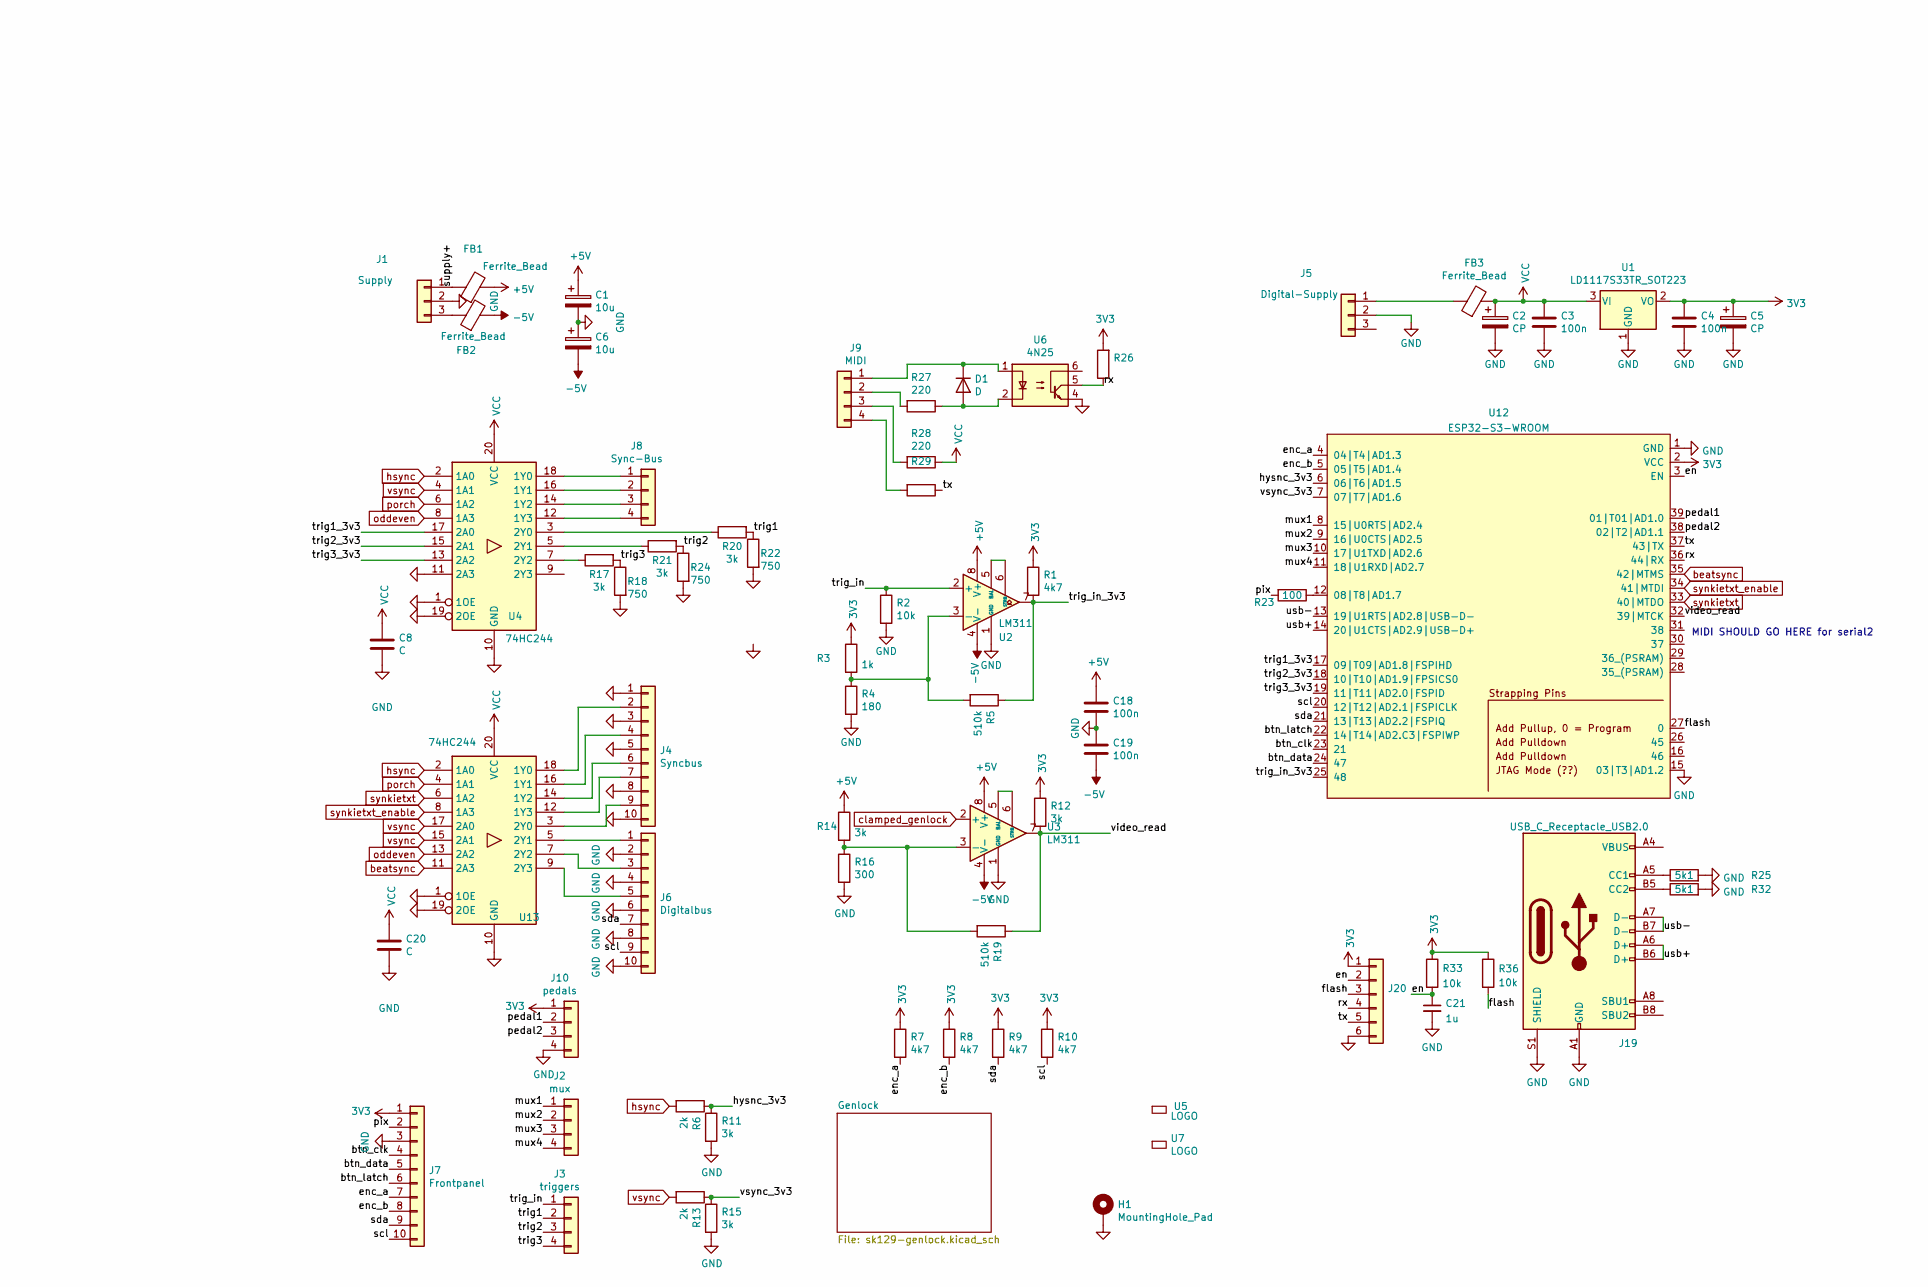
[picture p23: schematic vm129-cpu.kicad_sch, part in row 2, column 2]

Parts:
C1, C6: 10u; CP_EIA-3528-21_Kemet-B_Pad1.50x2.35mm_HandSolder
C2, C5: CP; CP_EIA-3528-21_Kemet-B_Pad1.50x2.35mm_HandSolder
C3, C4, C18, C19: 100n; C_0603_1608Metric_Pad1.05x0.95mm_HandSolder
C8, C20: C; R_0603_1608Metric_Pad1.05x0.95mm_HandSolder
C21: 1u; C_0603_1608Metric_Pad1.05x0.95mm_HandSolder
D1: D; D_MiniMELF
FB1, FB2, FB3: Ferrite_Bead; L_0805_2012Metric_Pad1.15x1.40mm_HandSolder
H1: MountingHole_Pad; MountingHole_2.7mm_M2.5_ISO7380_Pad
J1: Supply; Molex_KK-254_AE-6410-03A_1x03_P2.54mm_Vertical
J2: mux; Molex_KK-254_AE-6410-04A_1x04_P2.54mm_Vertical
J3: triggers; Molex_KK-254_AE-6410-04A_1x04_P2.54mm_Vertical
J4: Syncbus; IDC-Header_2x05_P2.54mm_Vertical
J5: Digital-Supply; Molex_KK-254_AE-6410-03A_1x03_P2.54mm_Vertical
J6: Digitalbus; IDC-Header_2x05_P2.54mm_Vertical
J7: Frontpanel; IDC-Header_2x05_P2.54mm_Vertical
J8: Sync-Bus; Molex_KK-254_AE-6410-04A_1x04_P2.54mm_Vertical
J9: MIDI; Molex_KK-254_AE-6410-04A_1x04_P2.54mm_Vertical
J10: pedals; Molex_KK-254_AE-6410-04A_1x04_P2.54mm_Vertical
J19: USB_C_Receptacle_USB2.0; JAE_USB-C_SJ122205
J20: Conn_01x06; AnymaPOGO-ISP
R1, R7, R8, R9, R10: 4k7; R_0805_2012Metric_Pad1.15x1.40mm_HandSolder
R2, R33, R36: 10k; R_0805_2012Metric_Pad1.15x1.40mm_HandSolder
R3: 1k; R_0805_2012Metric_Pad1.15x1.40mm_HandSolder
R4: 180; R_0805_2012Metric_Pad1.15x1.40mm_HandSolder
R5, R19: 510k; R_0805_2012Metric_Pad1.15x1.40mm_HandSolder
R6, R13: 2k; R_0805_2012Metric_Pad1.15x1.40mm_HandSolder
R11, R12, R14, R15, R17, R20, R21: 3k; R_0805_2012Metric_Pad1.15x1.40mm_HandSolder
R16: 300; R_0805_2012Metric_Pad1.15x1.40mm_HandSolder
R18, R22, R24: 750; R_0805_2012Metric_Pad1.15x1.40mm_HandSolder
R23: 100; R_0805_2012Metric_Pad1.15x1.40mm_HandSolder
R25, R32: 5k1; R_0805_2012Metric_Pad1.15x1.40mm_HandSolder
R26, R29: R_0805_2012Metric_Pad1.15x1.40mm_HandSolder
R27, R28: 220; R_0805_2012Metric_Pad1.15x1.40mm_HandSolder
U1: LD1117S33TR_SOT223; SOT-223-3_TabPin2
U2, U3: LM311; SOIC-8_3.9x4.9mm_P1.27mm
U4, U13: 74HC244; SO-20_12.8x7.5mm_P1.27mm
U5: LOGO; logo_anyma
U6: 4N25; DIP-6_W8.89mm_SMDSocket_LongPads
U7: LOGO; OSHW-Logo2_7.3x6mm_SilkScreen
U12: ESP32-S3-WROOM

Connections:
3V3: C4.1, C5.1, J7.1, J10.1, J20.1, R1.1, R3.1, R7.1, R8.1, R9.1, R10.1, R12.1, R26.2, R33.1, R36.1, U1.2 (VO), U12.2 (VCC)
+5V: C1.1, C18.1, FB1.2, R14.1, U2.8 (V+), U3.8 (V+); also elsewhere on the board
-5V: C6.2, C19.2, FB2.2, U2.4 (V-), U3.4 (V-); also elsewhere on the board
/btn_clk: J7.4, U12.23 (21)
/btn_data: J7.5, U12.24 (47)
/btn_latch: J7.6, U12.22 (14|T14|AD2.C3|FSPIWP)
/en: C21.1, J20.2, R33.2, U12.3 (EN)
/enc_a: J7.7, R7.2, U12.4 (04|T4|AD1.3)
/enc_b: J7.8, R8.2, U12.5 (05|T5|AD1.4)
/flash: J20.3, R36.2, U12.27 (0)
/hysnc_3v3: R6.1, R11.1, U12.6 (06|T6|AD1.5)
/mux1: J2.1, U12.8 (15|U0RTS|AD2.4)
/mux2: J2.2, U12.9 (16|U0CTS|AD2.5)
/mux3: J2.3, U12.10 (17|U1TXD|AD2.6)
/mux4: J2.4, U12.11 (18|U1RXD|AD2.7)
/pedal1: J10.2, U12.39 (01|T01|AD1.0)
/pedal2: J10.3, U12.38 (02|T2|AD1.1)
/pix: J7.2, R23.2
/rx: J20.4, R26.1, U6.5, U12.36 (44|RX)
/scl: J6.9, J7.10, R10.2, U12.20 (12|T12|AD2.1|FSPICLK)
/sda: J6.7, J7.9, R9.2, U12.21 (13|T13|AD2.2|FSPIQ)
/supply+: FB1.1, J1.1
/trig1: J3.2, R20.2, R22.1
/trig1_3v3: U4.17 (2A0), U12.17 (09|T09|AD1.8|FSPIHD)
/trig2: J3.3, R21.2, R24.1
/trig2_3v3: U4.15 (2A1), U12.18 (10|T10|AD1.9|FPSICS0)
/trig3: J3.4, R17.2, R18.1
/trig3_3v3: U4.13 (2A2), U12.19 (11|T11|AD2.0|FSPID)
/trig_in: J3.1, R2.1, U2.2 (+)
/trig_in_3v3: R1.2, R5.1, U2.7, U12.25 (48)
/tx: J20.5, R29.1, U12.37 (43|TX)
/usb+: J19.A6 (D+), J19.B6 (D+), U12.14 (20|U1CTS|AD2.9|USB-D+)
/usb-: J19.A7 (D-), J19.B7 (D-), U12.13 (19|U1RTS|AD2.8|USB-D-)
/video_read: R12.2, R19.1, U3.7, U12.32 (39|MTCK)
/vsync_3v3: R13.1, R15.1, U12.7 (07|T7|AD1.6)
GND: C1.2, C2.2, C3.2, C4.2, C5.2, C6.1, C8.2, C18.2, C19.1, C20.2, C21.2, H1.1, J1.2, J4.1, J4.3, J4.5, J4.8, J4.10, J5.2, J6.2, J6.4, J6.6, J6.8, J6.10, J7.3, J10.4, J19.A1 (GND), J19.A12 (GND), J19.B1 (GND), J19.B12 (GND), J19.S1 (SHIELD), J20.6, R2.2, R4.2, R11.2, R15.2, R16.2, R18.2, R22.2, R24.2, R25.2, R32.2, U1.1 (GND), U2.1 (GND), U3.1 (GND), U4.1 (1OE), U4.10 (GND), U4.11 (2A3), U4.19 (2OE), U6.4, U12.1 (GND), U12.15 (03|T3|AD1.2), U12.40 (GND), U12.41 (GND), U13.1 (1OE), U13.10 (GND), U13.19 (2OE); also elsewhere on the board
unnamed: D1.1 (K), J9.1, U6.1
unnamed: D1.2 (A), R27.1, U6.2
unnamed: FB2.1, J1.3
unnamed: FB3.1, J5.1
unnamed: J4.2, U13.18 (1Y0)
unnamed: J4.4, U13.16 (1Y1)
unnamed: J4.6, U13.14 (1Y2)
unnamed: J4.7, U13.12 (1Y3)
unnamed: J4.9, U13.3 (2Y0)
unnamed: J6.1, U13.5 (2Y1)
unnamed: J6.3, U13.7 (2Y2)
unnamed: J6.5, U13.9 (2Y3)
unnamed: J8.1, U4.18 (1Y0)
unnamed: J8.2, U4.16 (1Y1)
unnamed: J8.3, U4.14 (1Y2)
unnamed: J8.4, U4.12 (1Y3)
unnamed: J19.A4 (VBUS), J19.A9 (VBUS), J19.B4 (VBUS), J19.B9 (VBUS)
unnamed: J19.A5 (CC1), R25.1
unnamed: J19.B5 (CC2), R32.1
unnamed: R3.2, R4.1, R5.2, U2.3 (-)
unnamed: R14.2, R16.1, R19.2, U3.3 (-)
unnamed: R17.1, U4.7 (2Y2)
unnamed: R20.1, U4.3 (2Y0)
unnamed: R21.1, U4.5 (2Y1)
unnamed: R23.1, U12.12 (08|T8|AD1.7)
unnamed: J9.2, R27.2
unnamed: J9.3, R28.2
unnamed: J9.4, R29.2
unnamed: U2.5 (BAL), U2.6 (STRB)
unnamed: U3.5 (BAL), U3.6 (STRB)
VCC: C2.1, C3.1, C8.1, C20.1, FB3.2, R28.1, U1.3 (VI), U4.20 (VCC), U13.20 (VCC)
beatsync: U12.35 (42|MTMS), U13.11 (2A3)
clamped_genlock: U3.2 (+); also elsewhere on the board
hsync: R6.2, U4.2 (1A0), U13.2 (1A0); also elsewhere on the board
oddeven: U4.8 (1A3), U13.13 (2A2); also elsewhere on the board
porch: U4.6 (1A2), U13.4 (1A1); also elsewhere on the board
synkietxt: U12.33 (40|MTDO), U13.6 (1A2)
synkietxt_enable: U12.34 (41|MTDI), U13.8 (1A3)
vsync: R13.2, U4.4 (1A1), U13.15 (2A1), U13.17 (2A0); also elsewhere on the board

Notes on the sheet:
MIDI SHOULD GO HERE for serial2

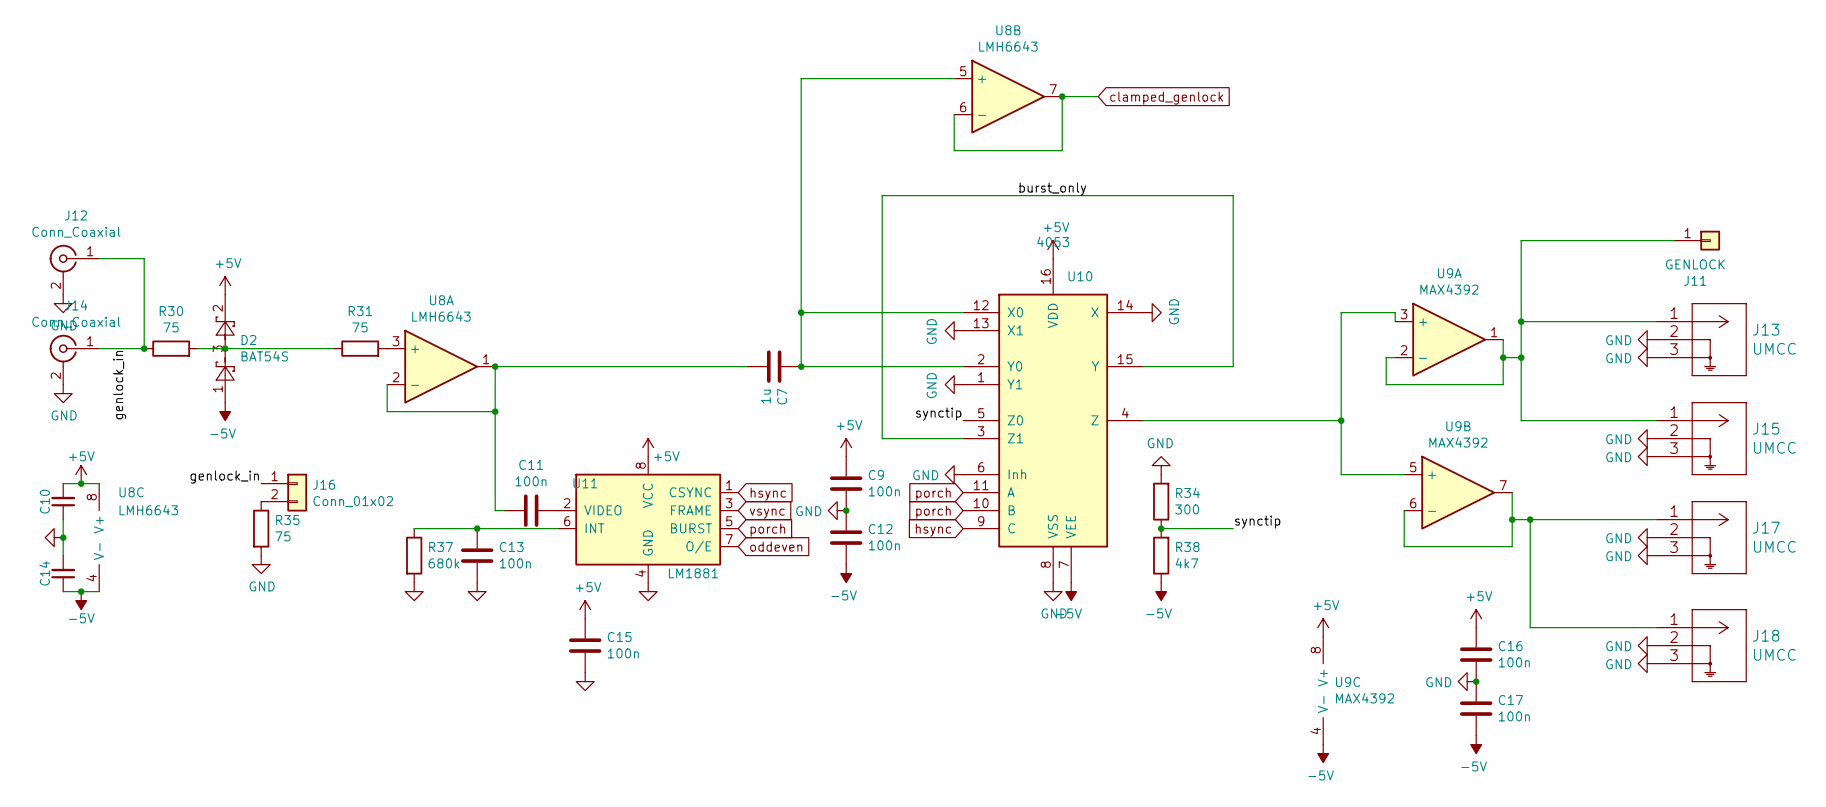
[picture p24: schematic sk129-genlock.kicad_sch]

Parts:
C7: 1u; C_1206_3216Metric_Pad1.42x1.75mm_HandSolder
C9, C10, C11, C12, C13, C14, C15, C16, C17: 100n; C_0603_1608Metric_Pad1.05x0.95mm_HandSolder
D2: BAT54S; SOT-23
J11: GENLOCK; Solderpad_1mm
J12, J14: Conn_Coaxial; BNC_MOLEX_0731000080_Horizontal
J13, J15, J17, J18: UMCC; TE_UMCC_2337019-1
J16: Conn_01x02; PinHeader_1x02_P2.54mm_Vertical
R30, R31, R35: 75; R_0805_2012Metric_Pad1.15x1.40mm_HandSolder
R34: 300; R_1206_3216Metric_Pad1.42x1.75mm_HandSolder
R37: 680k; R_0805_2012Metric_Pad1.15x1.40mm_HandSolder
R38: 4k7; R_1206_3216Metric_Pad1.42x1.75mm_HandSolder
U8: LMH6643; SOIC-8_3.9x4.9mm_P1.27mm
U9: MAX4392; SOIC-8_3.9x4.9mm_P1.27mm
U10: 4053; SOIC-16_3.9x9.9mm_P1.27mm
U11: LM1881; SOIC-8_3.9x4.9mm_P1.27mm

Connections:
+5V: C9.1, C10.2, C15.1, C16.1, D2.2, U8.8 (V+), U9.8 (V+), U10.16 (VDD), U11.8 (VCC); also elsewhere on the board
-5V: C12.2, C14.1, C17.2, D2.1, R38.1, U8.4 (V-), U9.4 (V-), U10.7 (VEE); also elsewhere on the board
/Genlock/burst_only: U10.3 (Z1), U10.15 (Y)
/Genlock/genlock_in: J12.1 (In), J14.1 (In), J16.1, R30.1
/Genlock/synctip: R34.1, R38.2, U10.5 (Z0)
GND: C9.2, C10.1, C12.1, C13.2, C14.2, C15.2, C16.2, C17.1, J12.2 (Ext), J13.2, J13.3, J14.2 (Ext), J15.2, J15.3, J17.2, J17.3, J18.2, J18.3, R34.2, R35.2, R37.2, U10.1 (Y1), U10.6 (Inh), U10.8 (VSS), U10.13 (X1), U10.14 (X), U11.4 (GND); also elsewhere on the board
unnamed: C7.1, U8.5 (+), U10.2 (Y0), U10.12 (X0)
unnamed: C11.1, U11.2 (VIDEO)
unnamed: C7.2, C11.2, U8.1, U8.2 (-)
unnamed: C13.1, R37.1, U11.6 (INT)
unnamed: D2.3, R30.2, R31.1
unnamed: J16.2, R35.1
unnamed: J17.1, J18.1, U9.6 (-), U9.7
unnamed: R31.2, U8.3 (+)
unnamed: J11.1, J13.1, J15.1, U9.1, U9.2 (-)
unnamed: U9.3 (+), U9.5 (+), U10.4 (Z)
clamped_genlock: U8.6 (-), U8.7; also elsewhere on the board
hsync: U10.9 (C), U11.1 (CSYNC); also elsewhere on the board
oddeven: U11.7 (O/E); also elsewhere on the board
porch: U10.10 (B), U10.11 (A), U11.5 (BURST); also elsewhere on the board
vsync: U11.3 (FRAME); also elsewhere on the board

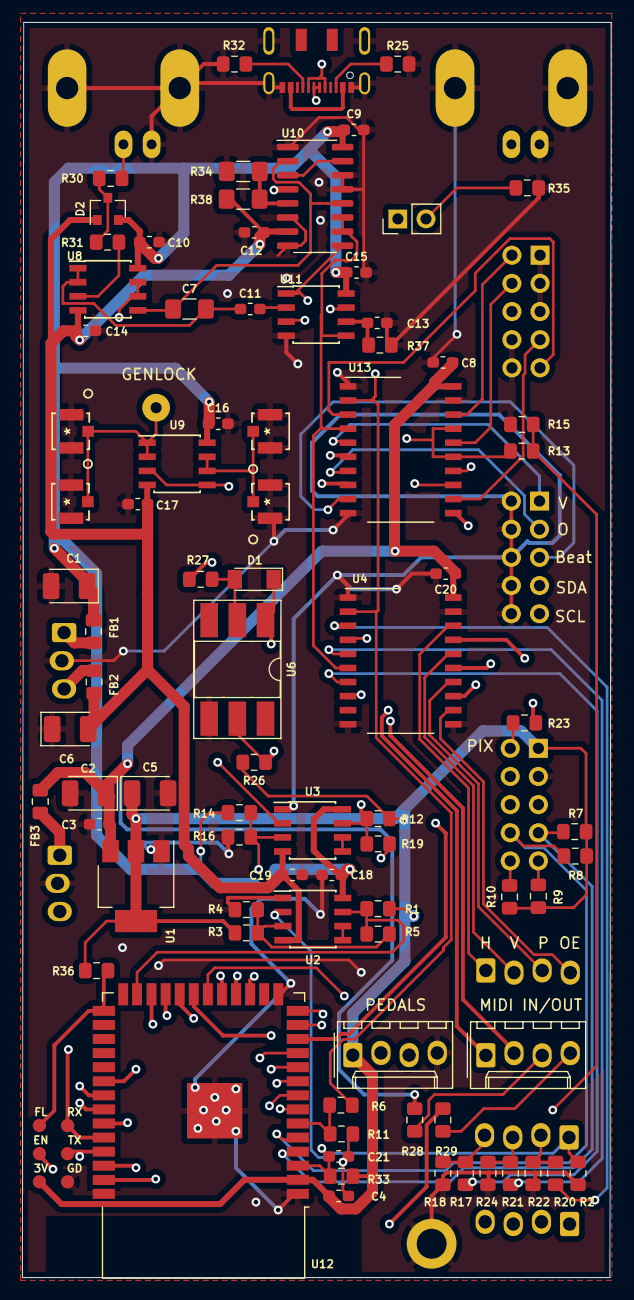
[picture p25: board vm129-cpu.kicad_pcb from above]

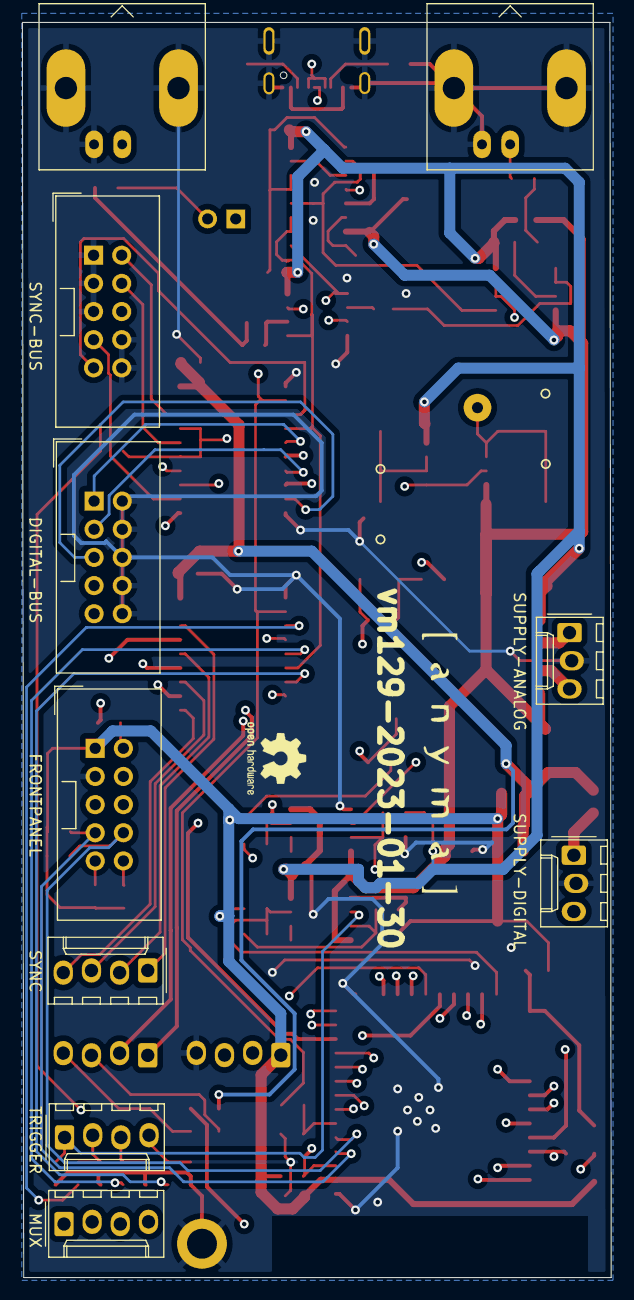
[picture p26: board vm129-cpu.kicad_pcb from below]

Board: 4 copper layers, 53.1 x 113.2 mm, 98 parts (12 on the bottom side), 88 nets.

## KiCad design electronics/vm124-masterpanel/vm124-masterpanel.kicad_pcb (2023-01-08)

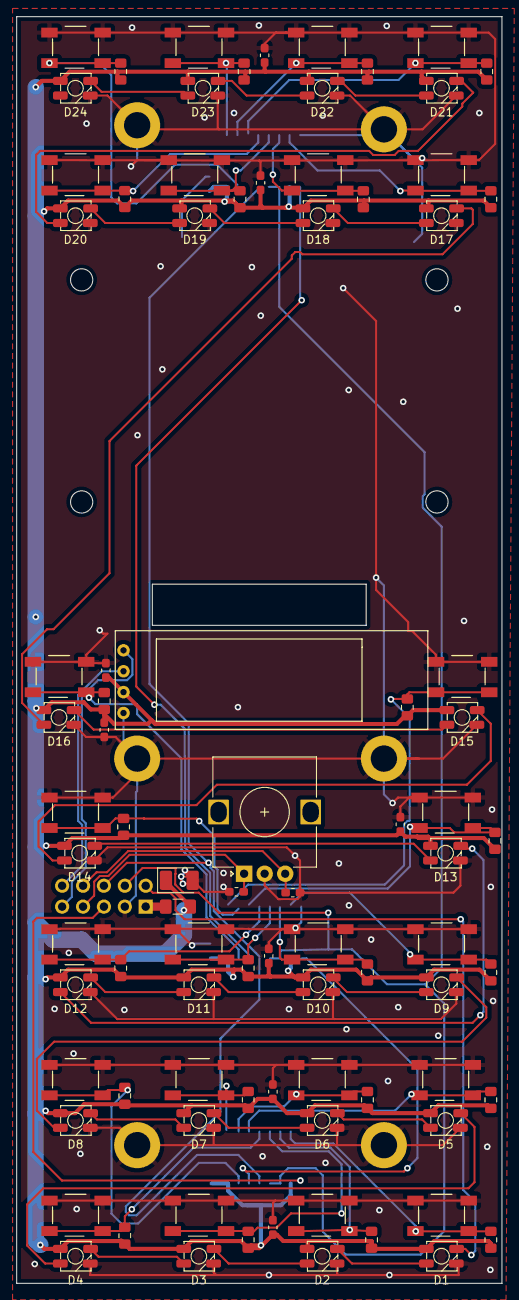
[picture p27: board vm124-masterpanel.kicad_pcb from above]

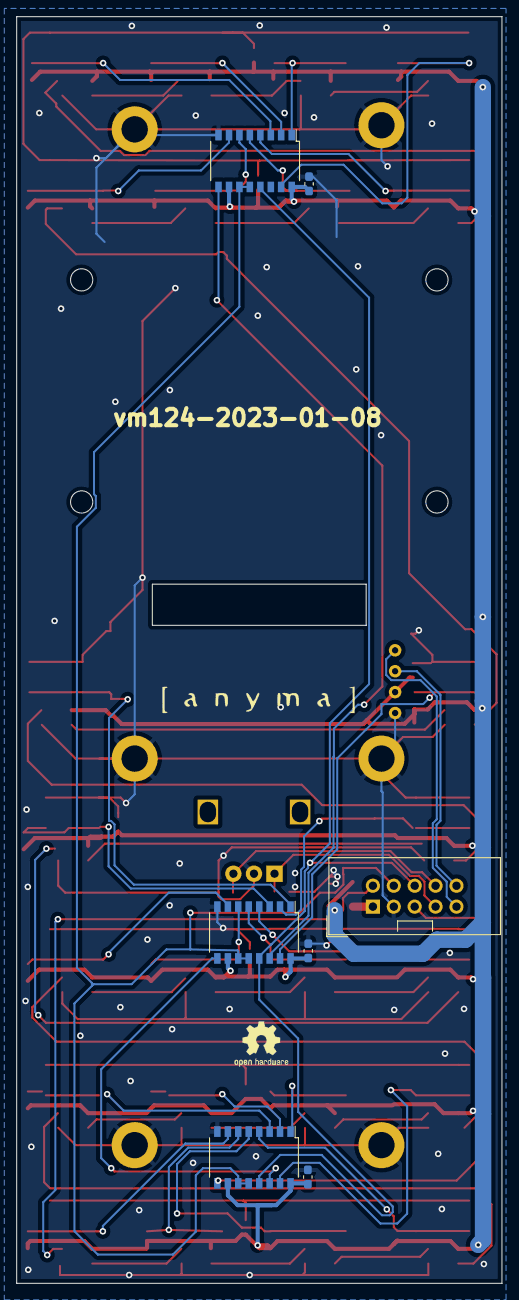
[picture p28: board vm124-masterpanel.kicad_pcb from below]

Board: 2 copper layers, 59.0 x 154.0 mm, 105 parts (9 on the bottom side), 60 nets.

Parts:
C1, C2, C3, C5, C6, C7, C8, C12, C13, C201, C202: C; C_0603_1608Metric_Pad1.05x0.95mm_HandSolder
C101: CP; CP_EIA-3528-21_Kemet-B_Pad1.50x2.35mm_HandSolder
C102, C103: 100n; C_0603_1608Metric_Pad1.05x0.95mm_HandSolder
D1, D2, D3, D4, D5, D6, D7, D8, D9, D10, D11, D12, D13, D14, D15, D16, D17, D18, D19, D20, D21, D22, D23, D24: SK6812MINI; SK6812-MINI-HS
FB101: Ferrite_Bead; L_1206_3216Metric_Pad1.42x1.75mm_HandSolder
H4, H5, H6, H7, H8, H9: MountingHole_Pad; MountingHole_3.2mm_M3_DIN965_Pad
H101, H102, H103, H104: MountingHole; MountingHole_2.7mm_M2.5
J101: Display; Bangood-OLED-128x32
J102: To-CPU; IDC-Header_2x05_P2.54mm_Vertical
R5, R6, R7, R8, R9, R10, R11, R12, R13, R14, R15, R16, R17, R18, R19, R20, R29, R30, R31, R32, R33, R34, R35, R36: R; R_0805_2012Metric_Pad1.15x1.40mm_HandSolder
SW5, SW6, SW7, SW8, SW9, SW10, SW11, SW12, SW13, SW14, SW15, SW16, SW17, SW18, SW19, SW20, SW29, SW30, SW31, SW32, SW33, SW34, SW35, SW36: SW_Push; Alps_Tactile_Switch
SW101: Rotary_Encoder; RotaryEncoder_Alps_EC12E_Vertical_H20mm
U2, U3, U5: 74LS597; SOP-16_4.4x10.4mm_P1.27mm
U101: LOGO; logo_anyma
U102: LOGO; OSHW-Logo2_7.3x6mm_SilkScreen

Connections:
/enc_a: C102.1, J102.7, SW101.A
/enc_b: C103.1, J102.8, SW101.B
/scl: J101.3, J102.10
/sda: J101.4, J102.9
GND: C1.2, C2.2, C3.2, C5.2, C6.2, C7.2, C8.2, C12.2, C13.2, C101.2, C102.2, C103.2, C201.2, C202.2, D1.2 (VSS), D2.2 (VSS), D3.2 (VSS), D4.2 (VSS), D5.2 (VSS), D6.2 (VSS), D7.2 (VSS), D8.2 (VSS), D9.2 (VSS), D10.2 (VSS), D11.2 (VSS), D12.2 (VSS), D13.2 (VSS), D14.2 (VSS), D15.2 (VSS), D16.2 (VSS), D17.2 (VSS), D18.2 (VSS), D19.2 (VSS), D20.2 (VSS), D21.2 (VSS), D22.2 (VSS), D23.2 (VSS), D24.2 (VSS), H4.1, H5.1, H6.1, H7.1, H8.1, H9.1, J101.1, J102.3, SW5.1, SW6.1, SW7.1, SW8.1, SW9.1, SW10.1, SW11.1, SW12.1, SW13.1, SW14.1, SW15.1, SW16.1, SW17.1, SW18.1, SW19.1, SW20.1, SW29.1, SW30.1, SW31.1, SW32.1, SW33.1, SW34.1, SW35.1, SW36.1, SW101.C, U2.8 (GND), U3.8 (GND), U5.8 (GND)
unnamed: D1.1 (DOUT), D2.3 (DIN)
unnamed: D2.1 (DOUT), D3.3 (DIN)
unnamed: D3.1 (DOUT), D4.3 (DIN)
unnamed: D4.1 (DOUT), D5.3 (DIN)
unnamed: D5.1 (DOUT), D6.3 (DIN)
unnamed: D6.1 (DOUT), D7.3 (DIN)
unnamed: D7.1 (DOUT), D8.3 (DIN)
unnamed: D8.1 (DOUT), D9.3 (DIN)
unnamed: D10.1 (DOUT), D11.3 (DIN)
unnamed: D9.1 (DOUT), D10.3 (DIN)
unnamed: D11.1 (DOUT), D12.3 (DIN)
unnamed: D12.1 (DOUT), D13.3 (DIN)
unnamed: D13.1 (DOUT), D14.3 (DIN)
unnamed: D14.1 (DOUT), D15.3 (DIN)
unnamed: D15.1 (DOUT), D16.3 (DIN)
unnamed: D16.1 (DOUT), D17.3 (DIN)
unnamed: D17.1 (DOUT), D18.3 (DIN)
unnamed: D18.1 (DOUT), D19.3 (DIN)
unnamed: D19.1 (DOUT), D20.3 (DIN)
unnamed: D20.1 (DOUT), D21.3 (DIN)
unnamed: D21.1 (DOUT), D22.3 (DIN)
unnamed: D22.1 (DOUT), D23.3 (DIN)
unnamed: D23.1 (DOUT), D24.3 (DIN)
unnamed: FB101.2, J102.1
unnamed: R5.2, SW5.2, U2.15 (A)
unnamed: R6.2, SW6.2, U2.1 (B)
unnamed: R7.2, SW7.2, U2.2 (C)
unnamed: R8.2, SW8.2, U2.3 (D)
unnamed: R9.2, SW9.2, U2.4 (E)
unnamed: R10.2, SW10.2, U2.5 (F)
unnamed: R11.2, SW11.2, U2.6 (G)
unnamed: R12.2, SW12.2, U2.7 (H)
unnamed: R13.2, SW13.2, U3.15 (A)
unnamed: R14.2, SW14.2, U3.1 (B)
unnamed: R15.2, SW15.2, U3.2 (C)
unnamed: R16.2, SW16.2, U3.3 (D)
unnamed: R17.2, SW17.2, U3.4 (E)
unnamed: R18.2, SW18.2, U3.5 (F)
unnamed: R19.2, SW19.2, U3.6 (G)
unnamed: R20.2, SW20.2, U3.7 (H)
unnamed: R29.2, SW29.2, U5.15 (A)
unnamed: R30.2, SW30.2, U5.1 (B)
unnamed: R31.2, SW31.2, U5.2 (C)
unnamed: R32.2, SW32.2, U5.3 (D)
unnamed: R33.2, SW33.2, U5.4 (E)
unnamed: R34.2, SW34.2, U5.5 (F)
unnamed: R35.2, SW35.2, U5.6 (G)
unnamed: R36.2, SW36.2, U5.7 (H)
unnamed: U2.9 (QH), U5.14 (SER)
unnamed: U3.14 (SER), U5.9 (QH)
VCC: C1.1, C2.1, C3.1, C5.1, C6.1, C7.1, C8.1, C12.1, C13.1, C101.1, C201.1, C202.1, D1.4 (VDD), D2.4 (VDD), D3.4 (VDD), D4.4 (VDD), D5.4 (VDD), D6.4 (VDD), D7.4 (VDD), D8.4 (VDD), D9.4 (VDD), D10.4 (VDD), D11.4 (VDD), D12.4 (VDD), D13.4 (VDD), D14.4 (VDD), D15.4 (VDD), D16.4 (VDD), D17.4 (VDD), D18.4 (VDD), D19.4 (VDD), D20.4 (VDD), D21.4 (VDD), D22.4 (VDD), D23.4 (VDD), D24.4 (VDD), FB101.1, J101.2, R5.1, R6.1, R7.1, R8.1, R9.1, R10.1, R11.1, R12.1, R13.1, R14.1, R15.1, R16.1, R17.1, R18.1, R19.1, R20.1, R29.1, R30.1, R31.1, R32.1, R33.1, R34.1, R35.1, R36.1, U2.10 (~R), U2.16 (VCC), U3.10 (~R), U3.16 (VCC), U5.10 (~R), U5.16 (VCC)
clk: J102.4, U2.11 (SCK), U2.12 (CLK), U3.11 (SCK), U3.12 (CLK), U5.11 (SCK), U5.12 (CLK)
cs: J102.6, U2.13 (~SLoad), U3.13 (~SLoad), U5.13 (~SLoad)
data: J102.5, U3.9 (QH)
pix: D1.3 (DIN), J102.2

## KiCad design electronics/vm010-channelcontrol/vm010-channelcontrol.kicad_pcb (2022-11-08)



Board: 4 copper layers, 30.0 x 181.4 mm, 64 parts (16 on the bottom side), 59 nets.

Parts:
C1: 10u; CP_EIA-3528-21_Kemet-B_Pad1.50x2.35mm_HandSolder
C2, C3, C4, C5, C101, C102, C103, C104, C105, C106: 100n; R_0603_1608Metric_Pad1.05x0.95mm_HandSolder
C6, C7: 10p; R_0805_2012Metric_Pad1.15x1.40mm_HandSolder
D1, D2, D3, D4, D5, D6, D7, D8, D9: SK6812MINI; SK6812-MINI-HS
D101: LED; LED_0805_2012Metric
FB101: Ferrite_Bead; L_0805_2012Metric_Pad1.15x1.40mm_HandSolder
H1, H2, H3, H5: MountingHole_Pad; MountingHole_2.7mm_M2.5_DIN965_Pad
J1: to-eq; IDC-Header_2x05_P2.54mm_Vertical
J3: Supply; Molex_KK-254_AE-6410-03A_1x03_P2.54mm_Vertical
J4, J5: Conn_01x02; Molex_KK-254_AE-6410-02A_1x02_P2.54mm_Vertical
J6: Conn_01x04; Molex_KK-254_AE-6410-04A_1x04_P2.54mm_Vertical
J101: Serial; Molex_KK-254_AE-6410-03A_1x03_P2.54mm_Vertical
J102: digitalbus; IDC-Header_2x05_P2.54mm_Vertical
R1, R102, R103, R104, R105, R106: 220; R_0805_2012Metric_Pad1.15x1.40mm_HandSolder
R2, R101: 560; R_0805_2012Metric_Pad1.15x1.40mm_HandSolder
RV1, RV2, RV3, RV5: R_POT; Potentiometer_Alps_RK09K_Single_Vertical
RV4: R_POT; Potentiometer_Alps_RS6011xP_Slide
SW1, SW2, SW3, SW4, SW5, SW6, SW7, SW8, SW9: SW_Push; Alps_Tactile_Switch
U1: AnymaISP; PinHeader_1x06_P2.54mm_Vertical
U3: MAX5741; MSOP-10_3x3mm_P0.5mm
U4: ADR510; SOT-23
U101: ATmega1284P-MU; QFN-44-1EP_7x7mm_P0.5mm_EP5.2x5.2mm
U102: LOGO; logo_anyma
U103: LOGO; OSHW-Logo2_7.3x6mm_SilkScreen
Y1: Crystal; Crystal_SMD_HC49-SD

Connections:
+5V: C4.1, FB101.2, J3.1, R2.1, U3.3 (VDD)
/aux-level: RV5.2, U101.35 (PA2|A2|26)
/bias-level: RV2.2, U101.30 (PA7|A7|31)
/bias_cv: J1.9, U3.9 (OUTC)
/bus_a: SW7.2, U101.16 (PD7|PWM|15)
/bus_b: SW8.2, U101.15 (PD6|PWM|14)
/bus_c: SW9.2, U101.14 (PD5|PWM|13)
/compa: SW2.2, U101.22 (PC3|TMS|19)
/compa-level: RV1.2, U101.31 (PA6|A6|30)
/compa_bypass: R104.2, U101.41 (PB1|1)
/compa_cv: J1.3, U3.8 (OUTB)
/dac2_select: J6.1, U101.32 (PA5|A5|29)
/dac_select: U3.1 (~CS), U101.33 (PA4|A4|28)
/drywet: SW4.2, U101.24 (PC5|TDI|21)
/edge_bypass: R103.2, U101.43 (PB3|PWM|AIN1|3)
/edges: SW1.2, U101.13 (PD4|PWM|12)
/extra_cv: J5.1, U3.10 (OUTD)
/invert: SW3.2, U101.23 (PC4|TDO|20)
/inverter_bypass: R105.2, U101.34 (PA3|A3|27)
/miso: U1.5 (MISO), U101.2 (PB6|PWM|MISO|6)
/mix-level: RV4.2, U101.36 (PA1|A1|25)
/mosi: J6.3, U1.6 (MOSI), U3.5 (DIN), U101.1 (PB5|MOSI|5)
/oddeven: J102.3, U101.21 (PC2TCK|18)
/pix: D1.3 (DIN), R1.1
/preview_bypass: J4.1, R106.2, U101.42 (PB2|INT2|AIN0|2)
/quantize_in: J102.5, U101.12 (PD3|TX1|INT1|11)
/rec|play|dub: SW5.2, U101.25 (PC6|22)
/reset: U1.3 (~RESET), U101.4 (~RESET)
/rx: J101.2, U101.9 (PD0|RX0|8)
/scale-level: RV3.2, U101.37 (PA0|A0|24)
/scale_cv: J1.1, U3.7 (OUTA)
/sck: J6.2, U1.4 (SCK), U3.2 (SCLK), U101.3 (PB7|PWM|SCK|7)
/scl: J102.9, U101.19 (PC0|SCL|16)
/sda: J102.7, U101.20 (PC1|SDA|17)
/stop|clear: SW6.2, U101.26 (PC7|23)
/tx: R102.2, U101.10 (PD1|TX0|9)
/vsync: J102.1, U101.11 (PD2|RX1|INT0|10)
GND: C1.2, C2.2, C3.2, C4.2, C5.2, C6.1, C7.2, C101.2, C102.2, C103.2, C104.2, C105.2, C106.2, D1.2 (VSS), D2.2 (VSS), D3.2 (VSS), D4.2 (VSS), D5.2 (VSS), D6.2 (VSS), D7.2 (VSS), D8.2 (VSS), D9.2 (VSS), D101.1 (K), H1.1, H2.1, H3.1, H5.1, J1.2, J1.4, J1.10, J3.2, J4.2, J5.2, J6.4, J101.3, J102.2, J102.4, J102.6, J102.8, J102.10, RV1.3, RV2.3, RV3.3, RV4.3, RV5.3, SW1.1, SW2.1, SW3.1, SW4.1, SW5.1, SW6.1, SW7.1, SW8.1, SW9.1, U1.1 (GND), U3.4 (GND), U4.2 (V-), U101.6 (GND), U101.18 (GND), U101.28 (GND), U101.39 (GND), U101.45 (GND)
unnamed: C5.1, U101.29 (AREF)
unnamed: C6.2, U101.8 (XTAL1), Y1.1
unnamed: C7.1, U101.7 (XTAL2), Y1.2
unnamed: D1.1 (DOUT), D2.3 (DIN)
unnamed: D2.1 (DOUT), D3.3 (DIN)
unnamed: D3.1 (DOUT), D4.3 (DIN)
unnamed: D4.1 (DOUT), D5.3 (DIN)
unnamed: D5.1 (DOUT), D6.3 (DIN)
unnamed: D6.1 (DOUT), D7.3 (DIN)
unnamed: D7.1 (DOUT), D8.3 (DIN)
unnamed: D8.1 (DOUT), D9.3 (DIN)
unnamed: D101.2 (A), R101.1
unnamed: J1.5, R103.1
unnamed: J1.6, R104.1
unnamed: J1.7, R105.1
unnamed: J1.8, R106.1
unnamed: J101.1, R102.1
unnamed: R1.2, U101.44 (PB4|PWM|SS|4)
unnamed: R2.2, U3.6 (REF), U4.1 (V+)
unnamed: R101.2, U101.40 (PB0|LED_BUILTIN|0)
VCC: C1.1, C2.1, C3.1, C101.1, C102.1, C103.1, C104.1, C105.1, C106.1, D1.4 (VDD), D2.4 (VDD), D3.4 (VDD), D4.4 (VDD), D5.4 (VDD), D6.4 (VDD), D7.4 (VDD), D8.4 (VDD), D9.4 (VDD), FB101.1, RV1.1, RV2.1, RV3.1, RV4.1, RV5.1, U1.2 (VCC), U101.5 (VCC), U101.17 (VCC), U101.27 (AVCC), U101.38 (VCC)

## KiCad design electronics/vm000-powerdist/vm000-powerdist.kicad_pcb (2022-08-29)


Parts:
C1, C4: 100u; CP_Radial_D10.0mm_P5.00mm
C2, C3, C5, C6: 1u; C_1206_3216Metric
D1, D2: LED; LED_0805_2012Metric_Pad1.15x1.40mm_HandSolder
F1, F2: Polyfuse; Fuse_0805_2012Metric_Pad1.15x1.40mm_HandSolder
H1, H2: MountingHole_Pad; MountingHole_3.2mm_M3_DIN965_Pad
J1, J2, J3, J4, J5, J6, J7, J8: Conn_01x03_Male; Molex_KK-254_AE-6410-03A_1x03_P2.54mm_Vertical
J9: INPUT; Molex_KK-254_AE-6410-03A_1x03_P2.54mm_Vertical
R1, R2: R; R_0805_2012Metric_Pad1.15x1.40mm_HandSolder

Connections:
+5V: C1.1, C2.1, C3.1, F1.1, J1.1, J2.1, J3.1, J4.1, J5.1, J6.1, J7.1, J8.1, R1.1
-5V: C4.2, C5.2, C6.2, F2.1, J1.3, J2.3, J3.3, J4.3, J5.3, J6.3, J7.3, J8.3, R2.2
GND: C1.2, C2.2, C3.2, C4.1, C5.1, C6.1, D1.1 (K), D2.2 (A), H1.1, H2.1, J1.2, J2.2, J3.2, J4.2, J5.2, J6.2, J7.2, J8.2, J9.2
unnamed: D1.2 (A), R1.2
unnamed: D2.1 (K), R2.1
unnamed: F1.2, J9.1
unnamed: F2.2, J9.3


Board: 2 copper layers, 21.0 x 83.0 mm, 23 parts (0 on the bottom side), 7 nets.

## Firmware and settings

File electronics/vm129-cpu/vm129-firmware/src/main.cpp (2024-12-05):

#define VERSION "2024-12-03"
//----------------------------------------------------------------------------------------
//
//  vMix CPU Firmware
//  Part of the vmix20 analog video mixer by [ a n y m a ]
//  Based on the Synkie, analog modular video processor, www.synkie.net
//
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
//----------------------------------------------------------------------------------------

/*
About sync

There are two sync mechanisms running interlocked in parallel on the mixer: Beat Clock and Video Sync

1) Beat Clock:
This clock ticks 24 times per beat, running either on an internal precision timer
set to a specific BPM, or driven externally via MIDI realtime messages.
Parameter automation runs in step with the beat clock. Trigger outputs as well. (???????? but synched to vsync, no???)
Clock period varies between ~30ms @ 80bpm down to ~11ms @ 220bpm

2) Video Sync:
Vertical blanking interrupts taken from the Genlock signal (via the LM1881) are the main
clock for all mixer operations. Most of digital communication and noisy behaviour (Neopixel updates)
should take place during vertical blanking.
Clock period: fixed at 20ms


*/
#include <Arduino.h>
#include <Preferences.h>
#include <Wire.h>
#include <WiFi.h>
#include <FastLED.h>
#include <Adafruit_GFX.h>
#include <Adafruit_SSD1306.h>
#include <ESP32Encoder.h>
#include <MIDI.h>

#include <WiFi.h>
#include <WiFiUDP.h>
#include <ESPmDNS.h>
#include <AppleMIDI.h>
USING_NAMESPACE_APPLEMIDI

APPLEMIDI_CREATE_DEFAULTSESSION_INSTANCE();
// ..................................................................................... PIN mapping

const int PIN_ENCODER_A = 4;
const int PIN_ENCODER_B = 5;
const int PIN_HSYNC = 6;
const int PIN_VSYNC = 7;
const int PIN_MUX_4 = 18;
const int PIN_MUX_3 = 17;
const int PIN_MUX_2 = 16;
const int PIN_MUX_1 = 15;

const int PIN_FOOTPEDAL = 1;
const int PIN_FOOTPEDAL_2 = 2;
const int PIN_TRIGGER_IN = 48;
const int PIN_BEATSYNC = 42;
const int PIN_TRIGGER_3 = 11;
const int PIN_TRIGGER_2 = 10;
const int PIN_TRIGGER_1 = 9;
const int PIN_SYNKIETXT_EN = 41;
const int PIN_SYNKIETXT = 40;
const int PIN_VIDEO_READ = 39;
const int PIN_PIXELS = 8;

const int PIN_BTN_LATCH = 14;
const int PIN_BTN_CLK = 21;
const int PIN_BTN_DATA = 47;
const int PIN_SDA = 13;
const int PIN_SCL = 12;
const int PIN_RX = 37;
const int PIN_TX = 38;

// ..................................................................................... Constants

const int NUM_PIXELS = 24;

const int SYNC_MODE_INTERN = 0;
const int SYNC_MODE_EXTERN_AUDIO = 1;
const int SYNC_MODE_EXTERN_MIDI = 2;

const int MENU_NONE = 0;
const int MENU_BRIGHTNESS = 1;
const int MENU_BPM = 2;
const int MENU_TRIGGER_1 = 11;
const int MENU_TRIGGER_2 = 12;
const int MENU_TRIGGER_3 = 13;

const int trigger_clocks[] = {6, 12, 24, 48, 96};
static const char *const trigger_strings[] = {"16th", "8th", "beats", "half", "bar"};

const int UI_TIMEOUT = 5000;

#define NUM_REGISTERS 3
#define SELECTION_COLOR CRGB::Gray
// ..................................................................................... SCREEN

#define SCREEN_WIDTH 128
#define SCREEN_HEIGHT 32
#define OLED_RESET -1
Adafruit_SSD1306 display = Adafruit_SSD1306(SCREEN_WIDTH, SCREEN_HEIGHT, &Wire, OLED_RESET);

/* for u8g2 library use : U8G2_SSD1306_128X32_UNIVISION_2_HW_I2C */

#define LOOP_STATE_EMPTY 0
#define LOOP_STATE_REC 1
#define LOOP_STATE_DUB 2
#define LOOP_STATE_PLAY 3
#define LOOP_STATE_STOPPED 4

#define BUTTON_COLOR CRGB(0, 5, 10)
#define PIX_LOOP 3
#define PIX_STOP 2

#define I2C_CALL_REC 0xF0
#define I2C_CALL_PLAY 0xF1
#define I2C_CALL_DUB 0xF2
#define I2C_CALL_STOP 0xF3
#define I2C_CALL_CLEAR 0xF4
#define I2C_CALL_STORE 0xB0
#define I2C_CALL_RECALL 0xB1
#define I2C_CALL_BRIGHTNESS 0xB2
#define I2C_CALL_VOLUME 0xC0
#define I2C_CALL_SET_CHAN 0xC1

//========================================================================================
//----------------------------------------------------------------------------------------
//																				GLOBALS

MIDI_CREATE_INSTANCE(HardwareSerial, Serial1, DIN_MIDI);

Preferences preferences;
ESP32Encoder encoder;
CRGB pixels[NUM_PIXELS];

int selected_menu;
int sync_mode;
int bpm;
int bpm_displayed;

int brightness;

long last_ui_interaction;
long last_beat;
long last_midi_clock;

volatile int interruptCounter;
int tickCounter;

const int beat_divider = 24; // MIDI CLOCk Ticks per beat

int beatclock_clocks = beat_divider;    // default output beat on trigger out 1
int trigger1_clocks = beat_divider * 4; // default output bar on trigger out 1x
int trigger2_clocks = beat_divider;     // default output beat on trigger out 2
int trigger3_clocks = beat_divider / 4; // default output 16ths on trigger out 3

hw_timer_t *beatClockTimer = NULL;
portMUX_TYPE beatClockTimerMux = portMUX_INITIALIZER_UNLOCKED;

bool display_needs_update;

int preview_out_channel;
int preview_out_afl;

char loop_state;

long buttons_raw;

void update_leds(void);
void update_display(void);

//----------------------------------------------------------------------------------------
//																		Intro
void intro()
{
    display.clearDisplay();
    display.setTextSize(1);
    display.setTextColor(WHITE);
    display.setCursor(22, 6);
    display.println(F("[ a n y m a ]"));
    display.setCursor(8, 16);
    display.setTextSize(2);
    display.println(F("ANYMIX-21"));
    display.display();
    fill_solid(pixels, NUM_PIXELS, CRGB::DarkBlue);
    FastLED.show();

    /*
        display.clearDisplay();
        display.setTextSize(1);
        display.setCursor(40,0);
        display.println(F("version"));
        display.setCursor(34,12);
        display.println(F(VERSION));
        display.display();
        delay(1000);
        */
}

//----------------------------------------------------------------------------------------
//																		set all trigger pins to low
void release_triggers(void *p)
{
    vTaskDelay(10);
    digitalWrite(PIN_TRIGGER_1, LOW);
    digitalWrite(PIN_TRIGGER_2, LOW);
    digitalWrite(PIN_TRIGGER_3, LOW);
    vTaskDelete(NULL);
}

void release_tick(void *p)
{
    // log_v("Release");
    vTaskDelay(2);
    digitalWrite(PIN_BEATSYNC, LOW);
    vTaskDelete(NULL);
}

//----------------------------------------------------------------------------------------
//                                                              MIDI Clock Timer
void check_clock()
{
    if (interruptCounter > 0)
    {

        portENTER_CRITICAL(&beatClockTimerMux);
        interruptCounter = 0;
        portEXIT_CRITICAL(&beatClockTimerMux);

        tickCounter++;

        if (sync_mode == SYNC_MODE_EXTERN_MIDI)
        {
            if (tickCounter % 24 == 0)
            {
                long this_beat = millis();
                bpm = 60000 / (this_beat - last_beat);
                last_beat = this_beat;
                if (bpm_displayed != bpm)
                    display_needs_update = true;
            }
        }

        DIN_MIDI.sendRealTime(midi::Clock);

        // if (tickCounter % beatclock_clocks == 0)
        digitalWrite(PIN_BEATSYNC, HIGH);
        if (tickCounter % trigger1_clocks == 0)
            digitalWrite(PIN_TRIGGER_1, HIGH);
        if (tickCounter % trigger2_clocks == 0)
            digitalWrite(PIN_TRIGGER_2, HIGH);
        if (tickCounter % trigger3_clocks == 0)
            digitalWrite(PIN_TRIGGER_3, HIGH);

        xTaskCreate(release_tick, "release_tick", 3000, NULL, 1, NULL);
        xTaskCreate(release_triggers, "release_triggers", 3000, NULL, 1, NULL);

        /* t.after(2, release_tick);
        t.after(10, release_triggers); */
        update_display(); // display update needs a lot of time. do it right after clock tick
                          //  (if necessary) in order to not skew clock timing
        update_leds();
    }
}

void IRAM_ATTR onTimer()
{
    portENTER_CRITICAL_ISR(&beatClockTimerMux);
    interruptCounter++;
    portEXIT_CRITICAL_ISR(&beatClockTimerMux);
}

void change_bpm()
{
    portENTER_CRITICAL(&beatClockTimerMux);
    interruptCounter = 0;
    portEXIT_CRITICAL(&beatClockTimerMux);

    timerAlarmWrite(beatClockTimer, 2500000 / bpm, true); // 60 000 000 microseconds / bpm / 24 (clocks per beat)
    timerAlarmEnable(beatClockTimer);
}

//----------------------------------------------------------------------------------------
//																		UI Timeout

void check_ui_timeout()
{

    if (millis() - last_ui_interaction > UI_TIMEOUT)
    {
        selected_menu = 0;
        display_needs_update = true;
    }

    if (sync_mode == SYNC_MODE_EXTERN_MIDI)
    {
        if (millis() - last_midi_clock > 1000)
        {
            Serial.println("Lost MIDI");
            sync_mode = SYNC_MODE_INTERN;
            display_needs_update = true;
            change_bpm(); // restart timer
        }
    }
}

//----------------------------------------------------------------------------------------
//																		Encoder
void check_encoder()
{
    if (encoder.getCount() == 0)
        return;

    switch (selected_menu)
    {
    case MENU_NONE:
        break;
    case MENU_BRIGHTNESS:
        brightness += encoder.getCount();
        if (brightness < 5)
            brightness = 5;
        if (brightness > 255)
            brightness = 255;
        FastLED.setBrightness(brightness);
        FastLED.show();
        display_needs_update = true;
        Wire.beginTransmission(0);
        Wire.write(I2C_CALL_BRIGHTNESS);
        Wire.write(brightness);
        Wire.endTransmission();
        break;
    case MENU_BPM:
        bpm += encoder.getCount();
        if (bpm < 60)
            bpm = 60;
        if (bpm > 240)
            bpm = 240;
        display_needs_update = true;
        change_bpm();
        break;
    case MENU_TRIGGER_1:
        trigger1_clocks += encoder.getCount();
        if (trigger1_clocks < 1)
            trigger1_clocks = 1;
        if (trigger1_clocks > 100)
            trigger1_clocks = 100;
        display_needs_update = true;
        break;
    case MENU_TRIGGER_2:
        trigger2_clocks += encoder.getCount();
        if (trigger2_clocks < 1)
            trigger2_clocks = 1;
        if (trigger2_clocks > 100)
            trigger2_clocks = 100;
        display_needs_update = true;
        break;
    case MENU_TRIGGER_3:
        trigger3_clocks += encoder.getCount();
        if (trigger3_clocks < 1)
            trigger3_clocks = 1;
        if (trigger3_clocks > 100)
            trigger3_clocks = 100;
        display_needs_update = true;
        break;
    default:
        break;
    }

    last_ui_interaction = millis();
    encoder.setCount(0);
}

//----------------------------------------------------------------------------------------
//																		Buttons
void set_preview_mux()
{
    digitalWrite(PIN_MUX_4, (preview_out_channel & 1));
    digitalWrite(PIN_MUX_3, (preview_out_channel & 2));
    digitalWrite(PIN_MUX_2, preview_out_afl);
}

void preview_press(int n)
{
    if (preview_out_channel == n)
    {
        preview_out_afl = ~preview_out_afl;
    }
    else
    {
        preview_out_channel = n;
    }
    set_preview_mux();
}

//----------------------------------------------------------------------------------------
//																				PLAY
void play()
{
    return;
    Wire.beginTransmission(0);
    Wire.write(I2C_CALL_PLAY);
    Wire.endTransmission();
    loop_state = LOOP_STATE_PLAY;
}
//----------------------------------------------------------------------------------------
//																				REC
void record()
{
    return;
    Wire.beginTransmission(0);
    Wire.write(I2C_CALL_REC);
    Wire.endTransmission();
    loop_state = LOOP_STATE_REC;
}
//----------------------------------------------------------------------------------------
//																				DUB
void overdub()
{
    switch (loop_state)
    {
    case LOOP_STATE_PLAY:
        Wire.beginTransmission(0);
        Wire.write(I2C_CALL_DUB);
        Wire.endTransmission();
        loop_state = LOOP_STATE_DUB;
        break;

    default:
        break;
    }
}
//----------------------------------------------------------------------------------------
//																				STOP
void stop()
{
    return;
    Wire.beginTransmission(0);
    Wire.write(I2C_CALL_STOP);
    Wire.endTransmission();
    loop_state = LOOP_STATE_STOPPED;
}
//----------------------------------------------------------------------------------------
//																				CLEAR
void clear_buffer()
{
    return;
    Wire.beginTransmission(0);
    Wire.write(I2C_CALL_CLEAR);
    Wire.endTransmission();
    loop_state = LOOP_STATE_EMPTY;
}

//----------------------------------------------------------------------------------------
//																				REC-BTN

void handle_rec_click()
{
    switch (loop_state)
    {
    case LOOP_STATE_EMPTY:
        record();
        break;
    case LOOP_STATE_REC:
        play();
        break;
    case LOOP_STATE_PLAY:
        overdub();
        break;
    case LOOP_STATE_DUB:
        play();
        break;
    case LOOP_STATE_STOPPED:
        play();
        break;
    }
}

//----------------------------------------------------------------------------------------
//																				STOP-BTN

void handle_stop_click()
{
    switch (loop_state)
    {
    case LOOP_STATE_EMPTY:
        clear_buffer();
        break;
    case LOOP_STATE_REC:
        clear_buffer();
        break;
    case LOOP_STATE_PLAY:
        stop();
        break;
    case LOOP_STATE_DUB:
        stop();
        break;
    case LOOP_STATE_STOPPED:
        clear_buffer();
        break;
    }
}

void check_buttons()
{
    static long old_buttons;
    static int old_footpedal;

    byte temp;
    buttons_raw = 0;

    SPI.beginTransaction(SPISettings(80000, LSBFIRST, SPI_MODE2));
    digitalWrite(PIN_BTN_LATCH, LOW);
    delayMicroseconds(100);
    digitalWrite(PIN_BTN_LATCH, HIGH);
    cli();
    for (int i = 0; i < NUM_REGISTERS; i++)
    {
        temp = ~SPI.transfer(0x00);
        buttons_raw |= (temp << (i * 8)); //((temp << 4) & 0xF0 ) | ((temp >> 4) & 0x0F);
    }
    sei();
    SPI.endTransaction();

    // log_v("Buttons_raw: %d", buttons_raw);

    int footpedal = digitalRead(PIN_FOOTPEDAL);
    if (old_footpedal != footpedal)
    {
        if (!footpedal)
        {
            handle_rec_click();
        }
        old_footpedal = footpedal;
    }

    if (old_buttons == buttons_raw)
        return;

    long triggers = ~old_buttons & buttons_raw;

    for (int i = 0; i < NUM_PIXELS; i++)
    {
        if (triggers & (1 << i))
        {
            switch (i)
            {
            case 2:
                handle_stop_click();
                break;
            case 3:
                handle_rec_click();
                break;
            case 12:
                selected_menu = MENU_BRIGHTNESS;
                break;
            case 13:
                selected_menu = MENU_BPM;
                break;
            case 15:
                selected_menu = MENU_NONE;
                break;
            case 22:
                selected_menu = MENU_TRIGGER_1;
                break;
            case 21:
                selected_menu = MENU_TRIGGER_2;
                break;
            case 20:
                selected_menu = MENU_TRIGGER_3;
                break;

            case 19:
                preview_press(0);
                break;
            case 18:
                preview_press(1);
                break;
            case 17:
                preview_press(2);
                break;
            case 16:
                preview_press(3);
                break;

            default:
                break;
            }
        }

        last_ui_interaction = millis();
        old_buttons = buttons_raw;
        display_needs_update = true;
    }
}

//----------------------------------------------------------------------------------------
//																		Leds

void update_leds()
{
    fill_solid(pixels, NUM_PIXELS, BUTTON_COLOR);
    for (int i = 0; i < NUM_PIXELS; i++)
    {
        if (buttons_raw & (1 << i))
        {
            pixels[i] = CRGB::Yellow;
        }
    }

    switch (selected_menu)
    {
    case MENU_BRIGHTNESS:
        pixels[12] = SELECTION_COLOR;
    case MENU_BPM:
        break;
        pixels[13] = SELECTION_COLOR;
    case MENU_TRIGGER_1:
        break;
        pixels[22] = SELECTION_COLOR;
        break;
    case MENU_TRIGGER_2:
        pixels[21] = SELECTION_COLOR;
        break;
    case MENU_TRIGGER_3:
        pixels[20] = SELECTION_COLOR;
        break;
    }

    switch (loop_state)
    {
    case LOOP_STATE_EMPTY:
        break;
    case LOOP_STATE_REC:
        pixels[PIX_LOOP] = CRGB::Red;
        pixels[PIX_STOP] = CRGB::Red;
        break;
    case LOOP_STATE_PLAY:
        pixels[PIX_LOOP] = CRGB::Green;
        pixels[PIX_STOP] = CRGB::Green;
        break;
    case LOOP_STATE_DUB:
        pixels[PIX_LOOP] = CRGB::Orange;
        pixels[PIX_STOP] = CRGB::Orange;
        break;
    case LOOP_STATE_STOPPED:
        pixels[PIX_LOOP] = CRGB::Yellow;
        pixels[PIX_STOP] = CRGB::Yellow;
        break;
    }

    CRGB preview_color;
    if (preview_out_afl)
        preview_color = SELECTION_COLOR;
    else
        preview_color = CRGB::Gold;
    pixels[19 - preview_out_channel] = preview_color;

    if (digitalRead(PIN_TRIGGER_1))
    {
        pixels[22] = CRGB::Blue;
    }
    if (digitalRead(PIN_TRIGGER_2))
    {
        pixels[21] = CRGB::Blue;
    }
    if (digitalRead(PIN_TRIGGER_3))
    {
        pixels[20] = CRGB::Blue;
    }

    FastLED.show();
}

//----------------------------------------------------------------------------------------
//																		Display
void update_display()
{

    if (millis() < 6000)
        return;
    if (!display_needs_update)
        return;
    display.clearDisplay();
    display.setTextSize(1);
    display.setTextColor(WHITE);

    bpm_displayed = bpm;

    switch (selected_menu)
    {
    case MENU_NONE:
        display.setCursor(0, 0);
        if (sync_mode == SYNC_MODE_EXTERN_AUDIO)
            display.print("EXT SYNC: AUDIO");
        else if (sync_mode == SYNC_MODE_EXTERN_MIDI)
            display.print("EXT SYNC: MIDI");
        else
            display.print("INTERNAL SYNC");

        display.setTextSize(2);
        display.setCursor(0, 14);
        display.print(bpm);
        display.print(" bpm");

        break;
    case MENU_BRIGHTNESS:
        display.setCursor(0, 0);
        display.print("BRIGHTNESS");

        display.setTextSize(2);
        display.setCursor(0, 14);
        display.print(brightness);
        break;
    case MENU_BPM:
        display.setCursor(0, 0);
        display.print("BPM");

        display.setTextSize(2);
        display.setCursor(0, 14);
        display.print(bpm);
        break;
    case MENU_TRIGGER_1:
        display.setCursor(0, 0);
        display.print("TRIGGER OUT 1");

        display.setTextSize(2);
        display.setCursor(0, 14);
        display.print(trigger1_clocks);
        break;
    case MENU_TRIGGER_2:
        display.setCursor(0, 0);
        display.print("TRIGGER OUT 2");

        display.setTextSize(2);
        display.setCursor(0, 14);
        display.print(trigger2_clocks);
        break;
    case MENU_TRIGGER_3:
        display.setCursor(0, 0);
        display.print("TRIGGER OUT 3");

        display.setTextSize(2);
        display.setCursor(0, 14);
        display.print(trigger3_clocks);
        break;
    default:
        break;
    }

    display.drawLine(0, 8, 128, 8, WHITE);
    display.display();
    display_needs_update = false;
}

//----------------------------------------------------------------------------------------
//																				MIDI

void test(byte channel, byte pitch, byte velocity)
{
    log_v("GOT %d %d", pitch, velocity);
}

//																		MIDI Clock
void handleMIDIClock()
{
    last_midi_clock = millis();
    if (sync_mode != SYNC_MODE_EXTERN_MIDI)
    {
        sync_mode = SYNC_MODE_EXTERN_MIDI;
        display_needs_update = true;

        log_v("GOT MIDI CLOCK");
        timerAlarmDisable(beatClockTimer);
        interruptCounter = 0;
        tickCounter = 0;
    }

    interruptCounter++;
}

//																		Control changfe

void handleMIDICtlchange(byte channel, byte ctl, byte val)
{
    log_v("CTL %d %d", ctl, val);

    int chann = ctl / 10 + 1;
    ctl %= 10;

    Wire.beginTransmission(chann);
    Wire.write(I2C_CALL_SET_CHAN);
    Wire.write(ctl);
    Wire.write(val);
    Wire.endTransmission();
}

void note_on(byte channel, byte pitch, byte velocity)
{
    log_v("NOTE %d %d", pitch, velocity);
    Wire.beginTransmission(1);
    Wire.write(I2C_CALL_VOLUME);
    Wire.endTransmission();
}
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
void loop()
{
    static long last_button_check, last_ui_check, last_encoder_check;
    if (millis() - last_button_check > 20)
    {
        check_buttons();
        last_button_check = millis();
    }
    if (millis() - last_ui_check > 1000)
    {
        check_ui_timeout();
        last_ui_check = millis();
    }
    if (millis() - last_encoder_check > 100)
    {
        check_encoder();
        last_encoder_check = millis();
    }
    // DIN_MIDI.read();
    MIDI.read();
    check_clock();
}

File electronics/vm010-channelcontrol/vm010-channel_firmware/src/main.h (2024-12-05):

#ifndef __MAIN_INCLUDED__
#define __MAIN_INCLUDED__

#include "Arduino.h"

#define DEBUG 1

const int NUM_PIXELS = 9;
const int NUM_BTNS = 9;
const int NUM_POTS = 5;
const int NUM_CHAN = 8;

#define PIN_LED_BUILTIN 0
#define PIN_COMPA_OUT 1
#define PIN_PREVIEW_OUT 2
#define PIN_EDGES_OUT 3
#define PIN_PIXELS 4
#define PIN_MOSI 5
#define PIN_MISO 6
#define PIN_SCK 7

#define PIN_RX 8
#define PIN_TX 9
#define PIN_VSYNC 10
#define PIN_BEAT 11
#define PIN_BTN_EDGES 12
#define PIN_BTN_BUS_C 13
#define PIN_BTN_BUS_B 14
#define PIN_BTN_BUS_A 15

#define PIN_SCL 16
#define PIN_SDA 17
#define PIN_ODDEVEN 18
#define PIN_BTN_COMPA 19
#define PIN_BTN_INVERT 20
#define PIN_BTN_DRYWET 21
#define PIN_BTN_REC 22
#define PIN_BTN_STOP 23

#define PIN_AD_SCALE A0
#define PIN_AD_MIX A1
#define PIN_AD_AUX A2
#define PIN_INVERT_OUT 27
#define PIN_DAC0_CS 28
#define PIN_DAC1_CS 29
#define PIN_AD_COMPA A6
#define PIN_AD_BIAS A7

#define EEPROM_BUS_C 0
#define EEPROM_BUS_B 1
#define EEPROM_BUS_A 2
#define EEPROM_INVERT 3
#define EEPROM_COMPA 4
#define EEPROM_PFL 5
#define EEPROM_EDGES 6
#define EEPROM_I2C_ADDRESS 7


// scalke bias pots are inversed on board as of dec2020
const char PIN_POT[NUM_POTS] = {PIN_AD_BIAS, PIN_AD_COMPA, PIN_AD_SCALE, PIN_AD_AUX, PIN_AD_MIX};
const char PIN_BTN[NUM_BTNS] = {PIN_BTN_REC, PIN_BTN_STOP, PIN_BTN_BUS_C, PIN_BTN_BUS_B, PIN_BTN_BUS_A, PIN_BTN_DRYWET, PIN_BTN_INVERT, PIN_BTN_COMPA, PIN_BTN_EDGES};

#define LOOP_QUANTIZE 24 // quantize loop length to beat
                         // TODO: make this parameter selectable from vm129

#define LOOP_STATE_EMPTY 0
#define LOOP_STATE_REC 1
#define LOOP_STATE_DUB 2
#define LOOP_STATE_PLAY 3
#define LOOP_STATE_STOPPED 4
#define LOOP_STATE_REC_WAITING 5
#define LOOP_STATE_PLAY_WAITING 6

#define ERROR_NONE 0
#define ERROR_NO_BEAT 1
#define ERROR_NO_SYNC 2

#define BUTTON_COLOR CRGB(0, 5, 10)
#define SELECTION_COLOR CRGB::Gray

#define I2C_CALL_REC 0xF0
#define I2C_CALL_PLAY 0xF1
#define I2C_CALL_DUB 0xF2
#define I2C_CALL_STOP 0xF3
#define I2C_CALL_CLEAR 0xF4
#define I2C_CALL_STORE 0xB0
#define I2C_CALL_RECALL 0xB1
#define I2C_CALL_BRIGHTNESS 0xB2
#define I2C_CALL_VOLUME 0xC0
#define I2C_CALL_SET_CHAN 0xC1

#define BUS_A 6
#define BUS_B 5
#define BUS_C 4
#define BUS_D 3
#define SCALE 2
#define COMPA 1
#define BIAS 0
#endif

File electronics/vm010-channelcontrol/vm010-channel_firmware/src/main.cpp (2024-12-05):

//----------------------------------------------------------------------------------------
//
//	vm010  Firmware
//
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
//----------------------------------------------------------------------------------------

/*

    VSync goes negative for ~240µs
    30µs/Led -> Fastled update for 9 LEDs takes about 270µs
        - that should still well be inside vertical blanking period
    SPI Speed for DAC: 1Mhz. Need to transfer 8 words = 64 bits -> ~128µs transfer, right?

    Theory of operation:
        -> no digital duties during active video portion
        -> only do calculations and ad conversion during active video
        -> ad sampling twice, output once for a bit of oversampling/smoothing of values
        -> output lags behind by one field


    To be able to record and playback automation synchronised to Midi Clock the actual output buffers
    are only updated every MIDI tick (~30ms @ 80bpm down to ~11ms @ 220bpm -> still fast enough for hand related movements)
    --> pots are sampled async,  actual decision what is being output happens in the midi tick handler


    ODD FIELD: (20ms total)
        write to leds (during blanking)
        wait 2ms (let voltage settle)
        then sample AD
    EVEN FIELD: (20ms total)
        update DAC (during blanking)
        check buttons (during blanking)
        recalculate leds
        wait 2ms
        then sample AD


*/

#include <Timer.h>
#include <SPI.h>
#include <EEPROM.h>
#include <Wire.h>

#include "FastLED.h"

#include "main.h"
#include "ChannelParam.h"

ChannelParam chan[NUM_CHAN];
/*"channels" per channel:
0 - BIAS
1 - COMPA
2 - SCALE
3 - AUX
4 - BUS_C
5 - BUS_B
6 - BUS_A
*/

Timer t;
CRGB pixels[NUM_PIXELS];
char loop_state;
char pfl_state;
char inverter_on;
char edges_on;

int rec_idx,
    playback_idx;
int rec_length = 0;

char button_changed;

int error = ERROR_NONE;

byte i2c_address;
volatile byte i2c_new_bytes;
volatile byte i2c_buf[32];

volatile int v_sync_interrupt_flag;
volatile int beat_interrupt_flag;

void check_ad(void *context);
void check_btns();
void check_sync();
void check_tick();
void dac_send(int dac, int channel, int send_val);
void handle_rec_click();
void playback_btns();
void power_on_dacs();
void set_dacs();
void update_leds();

//----------------------------------------------------------------------------------------
//																				AD
// update potentiometer values for each channel
void check_ad(void *context)
{
    for (int i = 0; i < 4; i++)
    {
        chan[i].ad(analogRead(PIN_POT[i]));
    }
    // LAST POTENTIOMETER (FADER) controls BUS-A, B and C

    int temp = analogRead(PIN_AD_MIX);
    temp = 1023 - temp;
    chan[BUS_C].ad(temp);
    chan[BUS_B].ad(temp);
    chan[BUS_A].ad(temp);
}

void dac_send(int dac, int channel, int send_val)
{
    int dac_pin = (dac == 0) ? PIN_DAC0_CS : PIN_DAC1_CS;
    digitalWrite(dac_pin, LOW);
    send_val = send_val << 2;
    send_val &= 1023 << 2;
    send_val |= channel << 12;
    SPI.transfer16(send_val);
    digitalWrite(dac_pin, HIGH);
}

void set_dacs()
{
    SPI.beginTransaction(SPISettings(1000000, MSBFIRST, SPI_MODE2));

    for (int i = 0; i < 3; i++)
    {
        dac_send(0, i, chan[i].get());
        check_tick();
    }

    for (int i = 0; i < 4; i++)
    {
        dac_send(1, 3 - i, chan[i + 3].out_enabled ? chan[i + 3].get() : 0);
        check_tick();
    }
    SPI.endTransaction();
}

//---------------------------------------------------------------------------------------------
void power_on_dacs()
{
    static int sendval = 0xf010;

    SPI.beginTransaction(SPISettings(1000000, MSBFIRST, SPI_MODE2));

    digitalWrite(PIN_DAC0_CS, LOW);
    delay(1);
    SPI.transfer16(sendval);
    digitalWrite(PIN_DAC0_CS, HIGH);
    digitalWrite(PIN_DAC1_CS, LOW);
    delay(1);
    SPI.transfer16(sendval);
    digitalWrite(PIN_DAC1_CS, HIGH);

    delay(100);

    digitalWrite(PIN_DAC0_CS, LOW);
    delay(1);
    SPI.transfer16(sendval);
    digitalWrite(PIN_DAC0_CS, HIGH);
    digitalWrite(PIN_DAC1_CS, LOW);
    delay(1);
    SPI.transfer16(sendval);
    digitalWrite(PIN_DAC1_CS, HIGH);

    SPI.endTransaction();
}

//----------------------------------------------------------------------------------------
//																				PLAY
void play()
{
    switch (loop_state)
    {
    case LOOP_STATE_EMPTY:
        break;

    case LOOP_STATE_REC_WAITING:
        break;

    case LOOP_STATE_REC:
        loop_state = LOOP_STATE_PLAY_WAITING;
        break;

    case LOOP_STATE_PLAY:
        break;

    case LOOP_STATE_PLAY_WAITING:
        break;

    case LOOP_STATE_DUB:
        loop_state = LOOP_STATE_PLAY;
        break;

    case LOOP_STATE_STOPPED:
        loop_state = LOOP_STATE_PLAY;
        break;

    default:
        break;
    }
}
//----------------------------------------------------------------------------------------
//																				REC
void record()
{
    // store start values to see if a pot has actually moved
    for (int i = 0; i < NUM_CHAN; i++)
    {
        chan[i].mark();
    }
    button_changed = 0;
    loop_state = LOOP_STATE_REC_WAITING;
}

//----------------------------------------------------------------------------------------
//																				DUB
void overdub()
{
    // store start values to see if a pot has actually moved
    for (int i = 0; i < NUM_CHAN; i++)
    {
        chan[i].mark();
    }
    loop_state = LOOP_STATE_DUB;
}

//----------------------------------------------------------------------------------------
//																				STOP
void stop()
{
    loop_state = LOOP_STATE_STOPPED;
}

//----------------------------------------------------------------------------------------
//																				CLEAR
void clear_buffer()
{
    for (int i = 0; i < NUM_CHAN; i++)
    {
        chan[i].clear();
    }
    loop_state = LOOP_STATE_EMPTY;
}

//---------------------------------------------------------------------------------------------
void v_sync_interrupt()
{
    v_sync_interrupt_flag++;
}

void check_sync()
{
    static int field;
    static long last_vsync;
    long vsync_timestamp;

    if (v_sync_interrupt_flag)
    {
        v_sync_interrupt_flag--;
        vsync_timestamp = millis();
        if (vsync_timestamp - last_vsync > 15)
        { // something is wrong otherwise, fields are 20ms
            field++;
            field %= 2;

            if (field)
            {
                FastLED.show();
            }
            else
            {
                check_tick();
                set_dacs();
                check_tick();
                check_btns();
                check_tick();
                update_leds();
            }
        }
        t.after(4, check_ad, (void *)0);
        last_vsync = vsync_timestamp;
    }
    else
    {
        if (millis() - last_vsync > 30)
        { // we've lost sync
            error = ERROR_NO_SYNC;
            fill_solid(pixels, NUM_PIXELS, CRGB::Red);
            FastLED.show();
        }
    }
}
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

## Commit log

2020-08-20 add first modules
    [stade1.kicad_pcb, vm001-input.kicad_pcb, vm001-input.sch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]
2020-08-20 add voltage divider at eq output
    [vm003-eq.sch, vm006-mixbus.sch]
2020-08-21 new inverter, added edges
    [vm003-eq.kicad_pcb, vm003-eq.sch]
2020-08-25 add channel logic
    [vm010-channelcontrol.kicad_pcb, vm010-channelcontrol.sch]
2020-08-25 new version with scabi, ready for fab
    [vm003-eq.kicad_pcb, vm003-eq.sch]
2020-10-13 add firmware
    [vm003-eq.kicad_pcb, vm010-channelcontrol.kicad_pcb, vm010-channelcontrol.sch]
2020-10-15 vm003-eq: corrected values to fix in/out impedance matching
    [vm003-eq.kicad_pcb, vm003-eq.sch]
2020-10-18 updated eq filter values
    [vm003-eq.kicad_pcb, vm003-eq.sch]
2020-11-06 vm003eq: cleanup schematics, multilayer board. vm001input modified microsynkie
    [vm001-input.kicad_pcb, vm001-input.sch, vm003-eq.kicad_pcb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]
2020-11-06 add power distribution
    [vm000-powerdist-B_Cu.gbr, vm000-powerdist-B_Mask.gbr, vm000-powerdist-B_Paste.gbr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]
2020-11-06 multilayer vm001-input
    [vm001-input.kicad_pcb, vm001-input.sch, vm003-eq.kicad_pcb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]
2020-11-08 1 in 4 out mix module, multilayer pcb
    [vm001-input.kicad_pcb, vm003-eq.kicad_pcb, vm005-mix.kicad_pcb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]
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2020-11-13 vm10 with mega1284, multilayer, ready for fab
    [vm001-input.kicad_pcb, vm010-channelcontrol.kicad_pcb, vm010-channelcontrol.sch]
2020-11-17 change vias to 0.8/0.4
    [vm005-mix.kicad_pcb]
2020-11-21 better scabi range
    [vm001-input.sch, vm003-eq.sch]
2020-11-22 add dry/wet to eq bus, add current limiting resistors
    [vm010-channelcontrol.kicad_pcb, vm010-channelcontrol.sch]
2020-11-23 schematics of unified analog section
    [vm013-analog-section.kicad_pcb, vm013-analog-section.sch, vm013-clamp.sch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]
2020-11-23 board layout
    [vm013-analog-section.kicad_pcb, vm013-analog-section.sch, vm013-clamp.sch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]
2020-11-24 levelshifter for sync inputs, cut out active video portion of genlock, diode follower on audio sync in
    [vm010-channelcontrol.kicad_pcb]
2020-11-30 add 3d files
    [mixer-cage.skp, mixer-cage~.skp, skizze3.skp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]
2020-11-30 add missing files
    [beatcalc.skp, beatcalc~.skp, vm008-splitter.kicad_pcb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]
2020-12-03 more gain in mixr
    [skizze3.skp, skizze3~.skp, vm005-mix.kicad_pcb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]
2020-12-03 gnd issing on genlock mux
    [vm009-cpu.sch]
2020-12-05 add testing firmware
    [vm005-mix.kicad_pcb, vm005-mix.sch, vm005-unit.sch]
2020-12-08 correct dry/wet sync and burst resyncing. clean up layout
    [vm010-channelcontrol.kicad_pcb, vm010-channelcontrol.sch, vm010J-channelcontrol.kicad_pcb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]
2020-12-08 add some 3d files
    [mixer-cage2.skp, mixer-cage2~.skp]
2020-12-08 add mixer testrig
    [vm005-mix.kicad_pcb, vm005-mix.sch, vm005-unit.sch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]
2020-12-14 store button state in eeprom
    [vm005-mix.kicad_pcb, vm013-analog-section.kicad_pcb, vm013-levelmeter.sch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]
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2020-12-27 compa more black
    [vm010-channelcontrol.kicad_pcb, vm013-analog-section.kicad_pcb, vm013-clamp.sch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]
2020-12-28 add vm020
    [vm013-clamp.sch, vm013-eq.sch, vm013-mechanical.sch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]
2020-12-28 vm20-output: new low clip
    [vm013-mechanical.sch, vm020-output.sch, vm020-resync.sch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]
2020-12-29 nex gen architecture. input/mixer/output schematic
    [vm005-unit.sch, vm013-analog-section.sch, vm013-eq.sch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]
2021-01-01 vm101 board layout
    [vm013-mechanical.sch, vm101-clamp.sch, vm101-inout.sch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]
2021-01-02 add master faders
    [vm122-masterfader.kicad_pcb, vm122-masterfader.sch, vm122-phase.sch]
2021-01-03 add umcc connectors. close jumper for fcc shield to eq
    [vm009-cpu.sch, vm101-inout.kicad_pcb, vm101-inout.sch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]
2021-01-03 add umcc
    [vm113-effects.kicad_pcb, vm113-effects.sch, vm113-mechanical.sch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]
2021-01-03 ne version of cpu. bnc input, umcc out. recreation of genlock signal
    [beatcalc.skp, beatcalc~.skp, vm113-effects.kicad_pcb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]
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2021-01-04 connect missing nets. flip fcc connector
    [vm113-effects.kicad_pcb, vm113-effects.sch]
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2021-01-18 buttons, leds and basic menus
    [vm122-masterfader.kicad_pcb]
2021-01-21 attempt to better clamp genlock input with lt1228. lots of ringing
    [vm123-genlock-in.kicad_pcb, vm123-genlock-in.sch]
2021-02-03 correct bat54 footprint. non log scale input
    [vm120-output.kicad_pcb, vm120-output.sch, vm120-resync.sch]
2021-02-03 try correct resync impedance. add synkietxt input
    [vm120-resync.sch]
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2021-02-04 add gndjumpers. production ready
    [vm120-output.kicad_pcb, vm120-output.sch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]
2021-02-05 new clamp, synkietxt. reeady for fab
    [sk129-genlock.sch, vm129-cpu.kicad_pcb, vm129-cpu.sch]
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2021-02-12 mod for better burst
    [vm101-clamp.sch, vm101-resync.sch]
2021-03-14 version before going to langenthal
    [vm101-inout.kicad_pcb, vm120-output.kicad_pcb, vm123-genlock-in.kicad_pcb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]
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2022-08-29 add gain to videoinput to have 0-1V range (synkie style). kicad6
    [vm000-powerdist-B_Cu.gbr, vm000-powerdist-B_Mask.gbr, vm000-powerdist-B_Paste.gbr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]
2022-11-08 update to kicad 6. change sk6812 to hand solder version
    [vm010-channelcontrol.kicad_sch]
2022-11-08 update to 6.0. change footprints to sk6812-hs
    [vm102-inputs.kicad_sch]
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2023-01-02 add comment about scaling back PFL levels before resyncing
    [vm101-inout.kicad_sch]
2023-01-08 change neopixel to handsolder version
    [vm124-masterpanel.kicad_pcb, vm124-masterpanel.kicad_sch]
2023-01-30 correct burst gain on genlock out
    [vm129-cpu.kicad_sch]
2023-01-30 add buffers, change to esp32-s3
    [vm129-cpu.kicad_sch]
2023-01-31 add vm130 audio out
    [vm130-audio-out.kicad_pcb, vm130-audio-out.kicad_sch, vm130-channel.kicad_sch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]
2023-01-31 vm129 new board layout
    [sk129-genlock.kicad_sch, vm129-cpu.kicad_pcb, vm129-cpu.kicad_sch]
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2023-05-01 correct connections and resistor values for 3.3V MIDI
    [vm129-cpu.kicad_sch]
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2024-12-05 apple midi channel control
    [vm101-clamp.kicad_sch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]

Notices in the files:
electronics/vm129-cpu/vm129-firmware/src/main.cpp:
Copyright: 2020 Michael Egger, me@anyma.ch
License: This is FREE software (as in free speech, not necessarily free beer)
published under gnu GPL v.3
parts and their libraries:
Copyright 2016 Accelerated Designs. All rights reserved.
